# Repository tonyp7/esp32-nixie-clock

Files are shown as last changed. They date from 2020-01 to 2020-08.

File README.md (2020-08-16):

# esp32-nixie-clock

A smart nixie clock capable of automatically setting time and adjusting for timezones / summer time transitions.

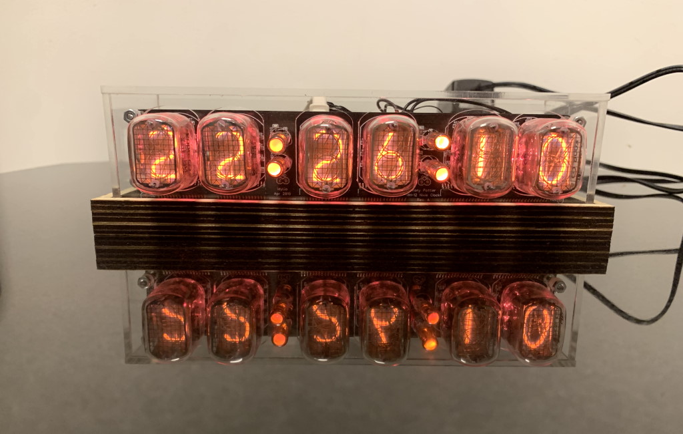
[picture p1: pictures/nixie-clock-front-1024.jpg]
Clock face


# Features

**Smart**

  - Time is set automatically through a web API
  - A webapp is provided to adjust wifi settings, timezone, backlights and display sleeping times
  
The wifi settings are managed by [esp32-wifi-manager](https://github.com/tonyp7/esp32-wifi-manager).

<p align="center">
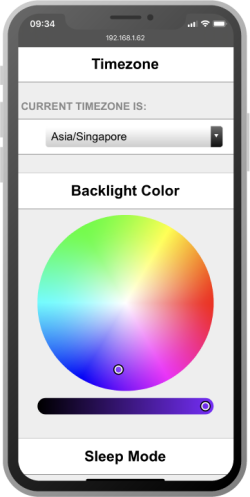
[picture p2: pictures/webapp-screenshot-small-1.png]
  
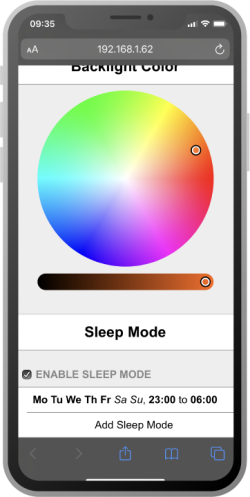
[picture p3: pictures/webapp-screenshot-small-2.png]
  
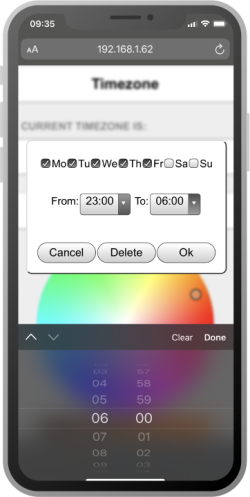
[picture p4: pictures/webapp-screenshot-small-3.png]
  
</p>

**A modern dispay driver**

  - SPI based driver
  - No multiplexing of nixies
  - No relying on old nixie drivers

Each pin is fully driven by its individual 300V NPN transistor.

**A robust high voltage converter**

 - A modern flyback converter with top of the line controller
 - No 555, no old 34063 trickery

The nixie clock is powered by a LT3757 controller and a big 1:10 transformer. The design can be found [here](https://github.com/tonyp7/170v-nixie-power-supply). The last thing you need is for your clock to catch fire!

# Repository structure

- bom: Bill of Materials for the PCBs
- nixie_clock_code: An esp-idf project to compile and flash on an ESP32
- pcb: PCB source files and renders for the clock
- pictures: A placeholder for the pictures you are seeing in this readme file
- schematics: Electronics schematics for the clock

# Photos

### Clock in its environment
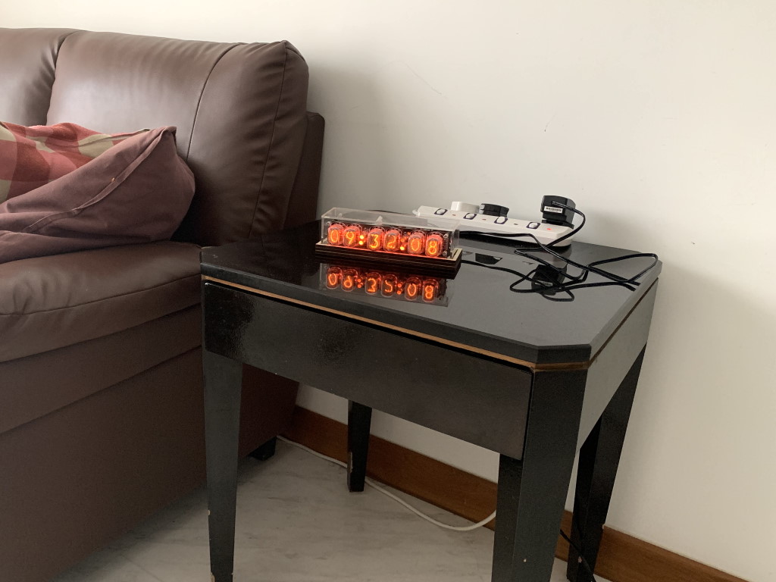
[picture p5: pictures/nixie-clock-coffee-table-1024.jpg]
Nixie Clock


### The clock face PCB
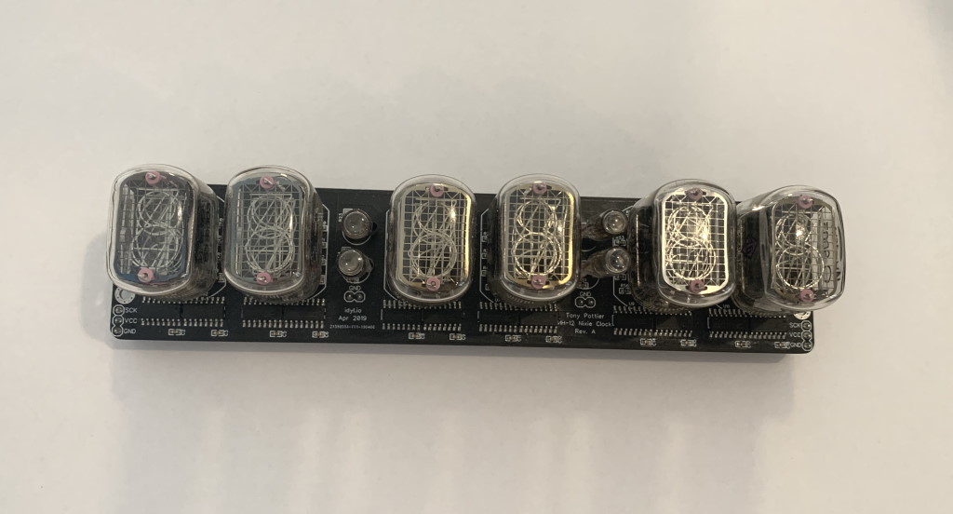
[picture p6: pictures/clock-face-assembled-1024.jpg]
Clock face PCB


### The logic board PCB
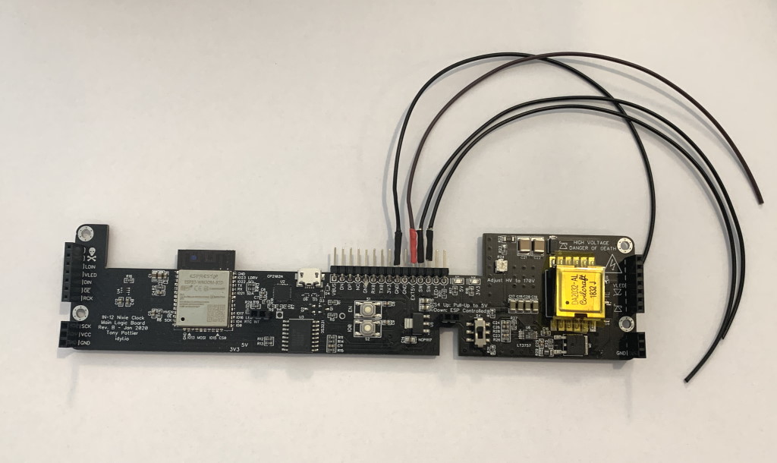
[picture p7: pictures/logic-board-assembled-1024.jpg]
Logic board PCB PCB


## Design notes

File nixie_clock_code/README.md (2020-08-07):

# Firmware for the esp32

This folder contains an esp-idf project for the esp32 powering the clock.

esp-idf 4.2+ is required to compile this code.

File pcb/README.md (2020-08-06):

# clock-face

Clock face assembled

# logic-board

Logic board assembled

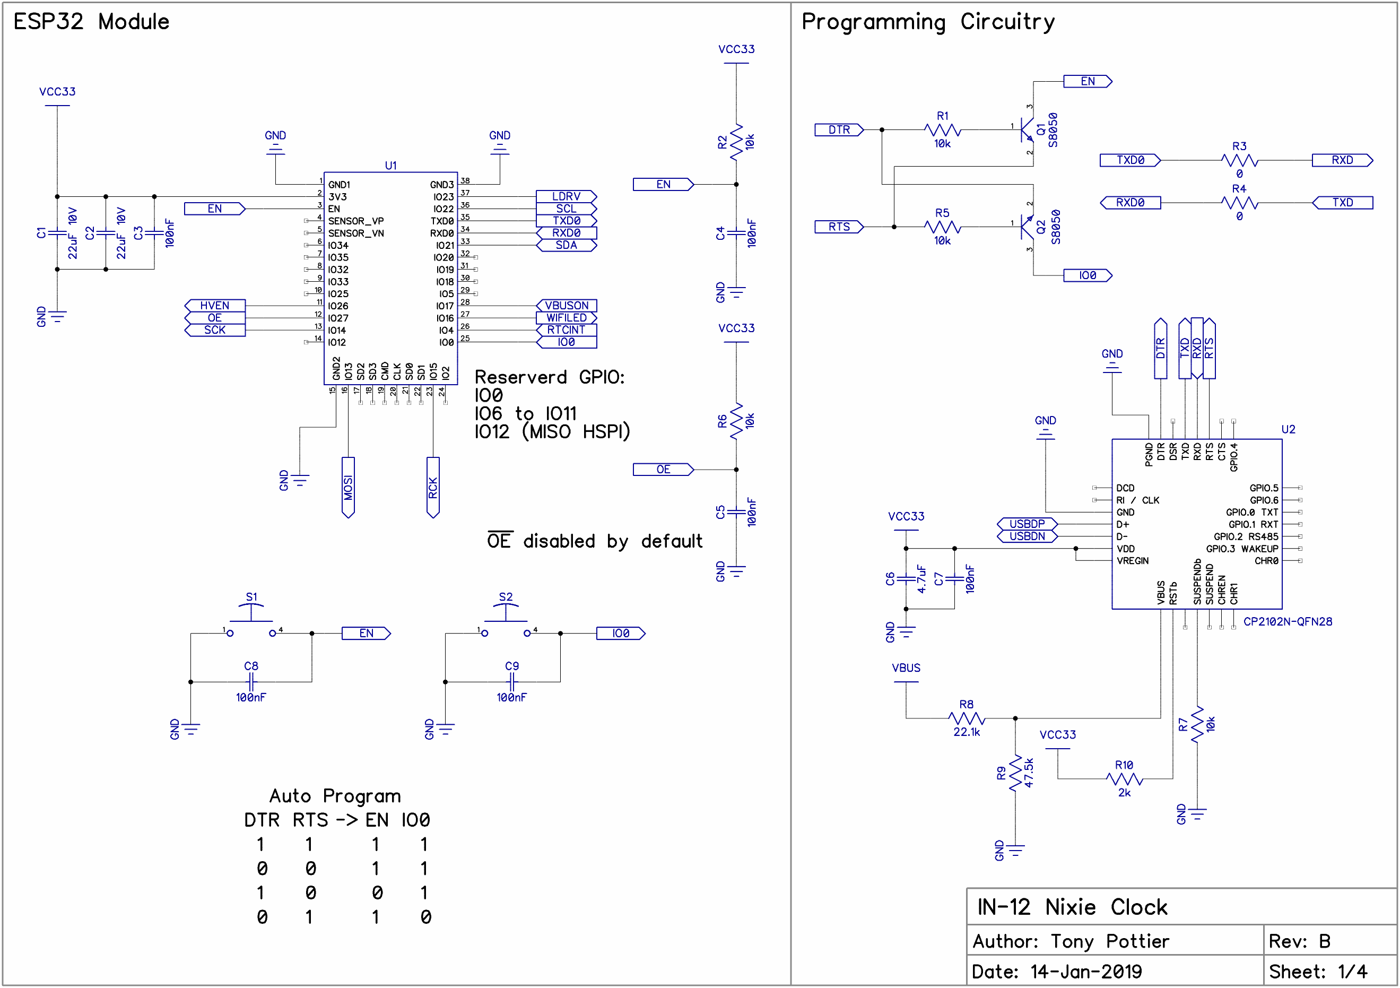
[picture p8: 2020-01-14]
schematics/logic-board/logic-board-schematics-sheet-1.png

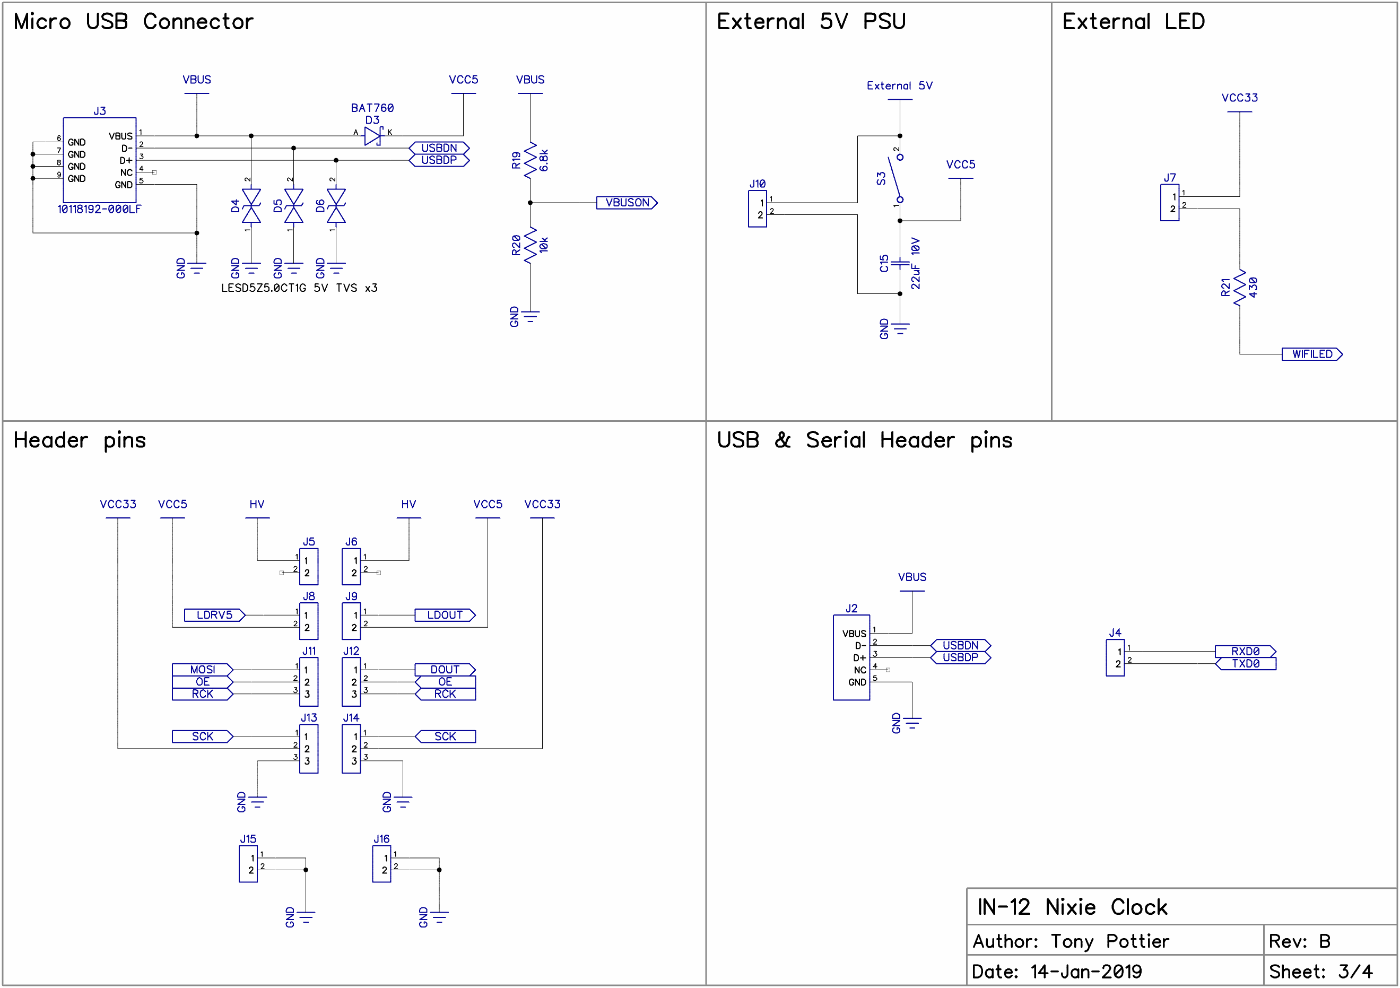
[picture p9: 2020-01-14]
schematics/logic-board/logic-board-schematics-sheet-3.png

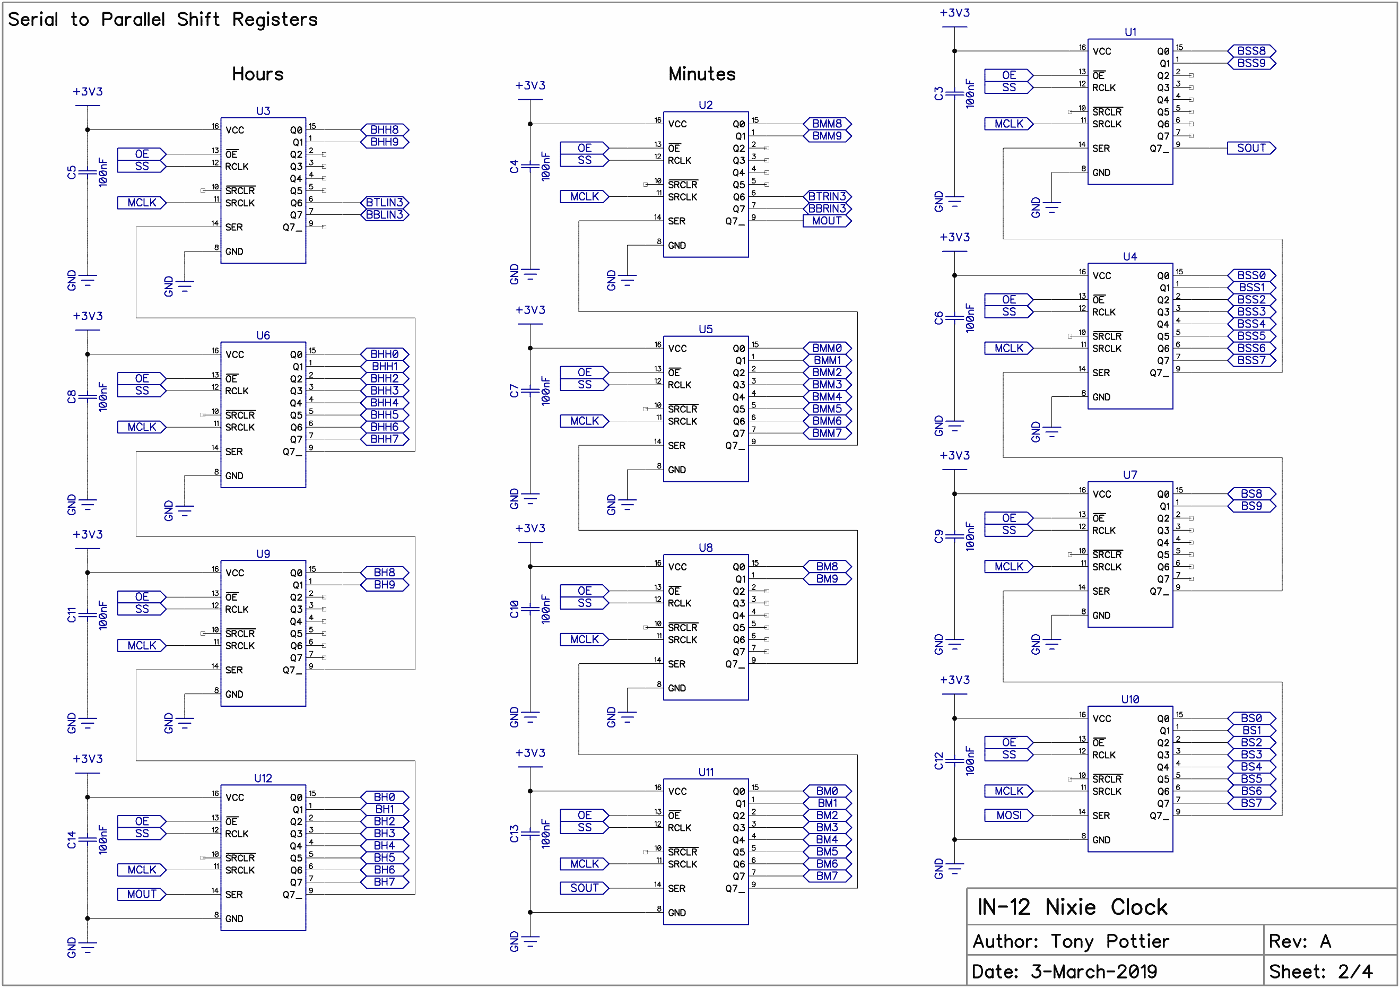
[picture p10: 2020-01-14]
schematics/clock-face/clock-face-schematics-sheet-2.png

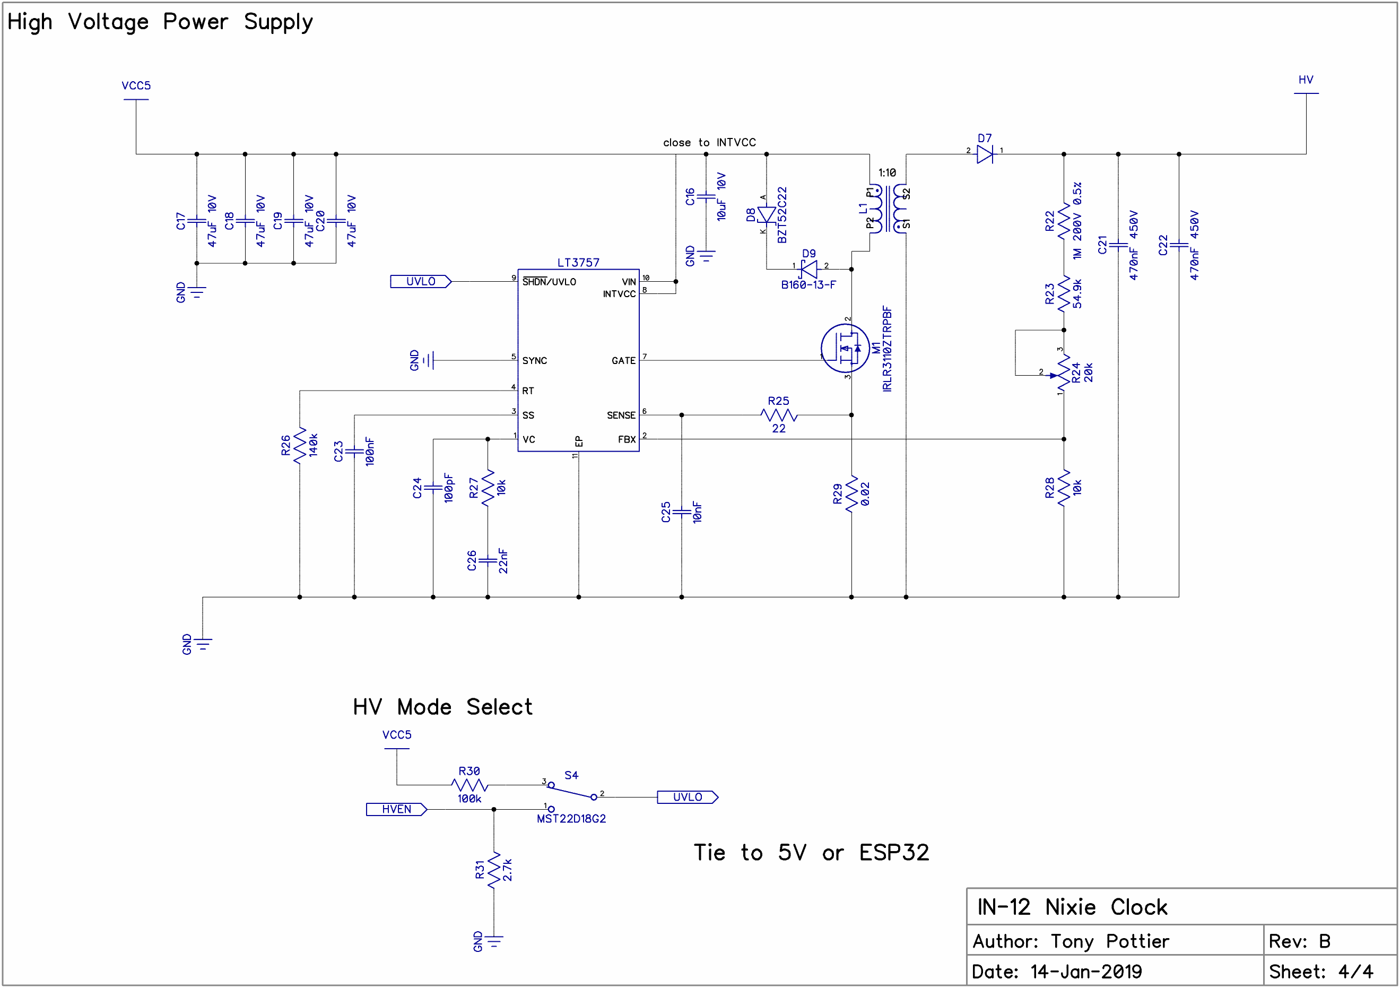
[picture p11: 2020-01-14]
schematics/logic-board/logic-board-schematics-sheet-4.png

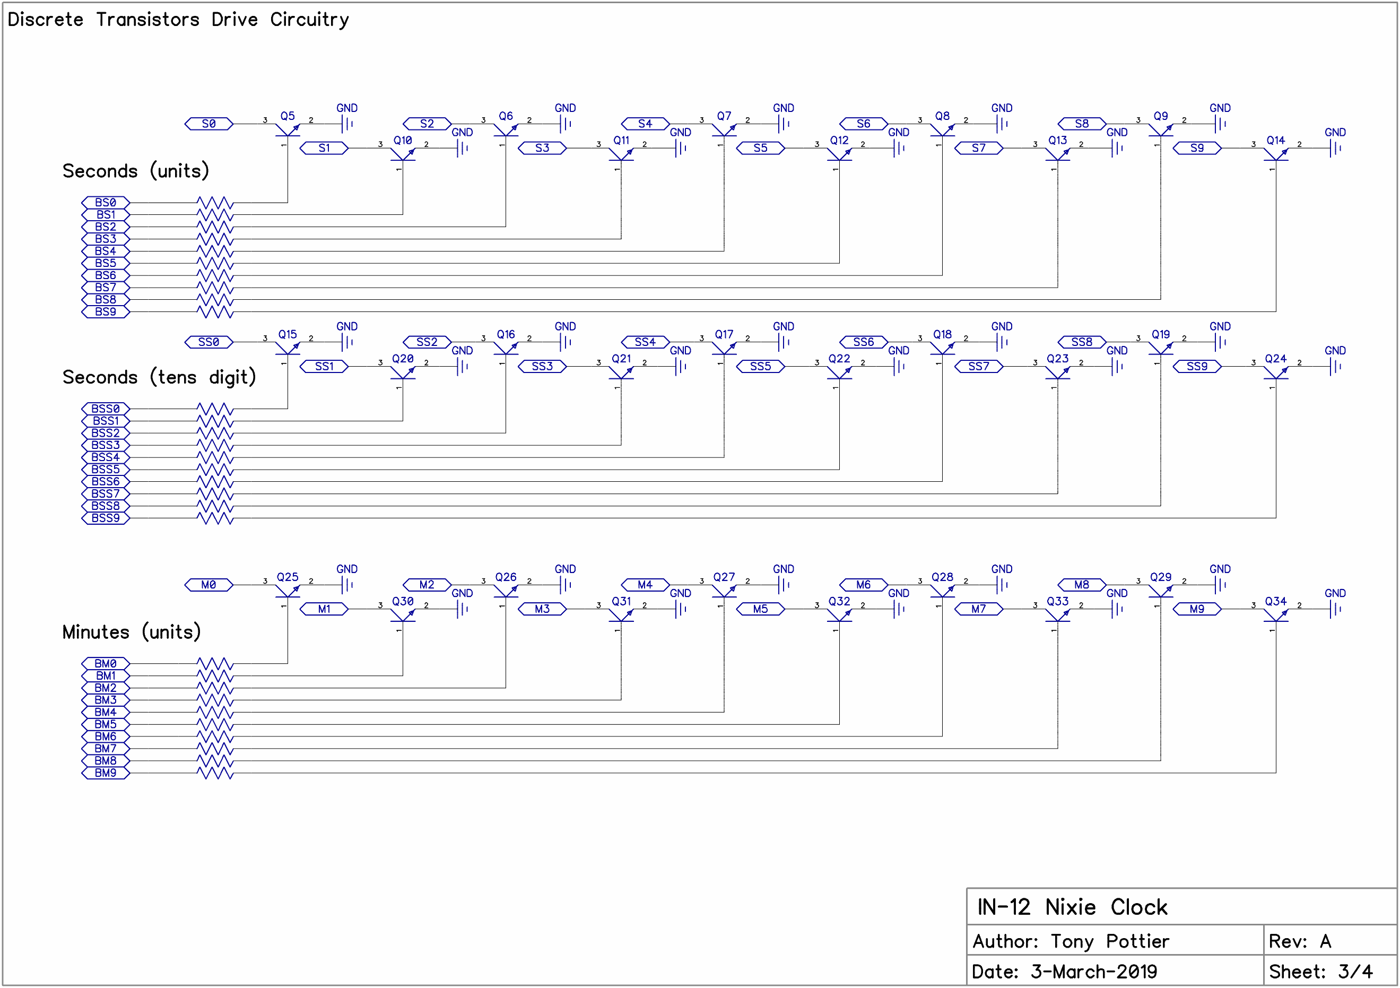
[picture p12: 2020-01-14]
schematics/clock-face/clock-face-schematics-sheet-3.png

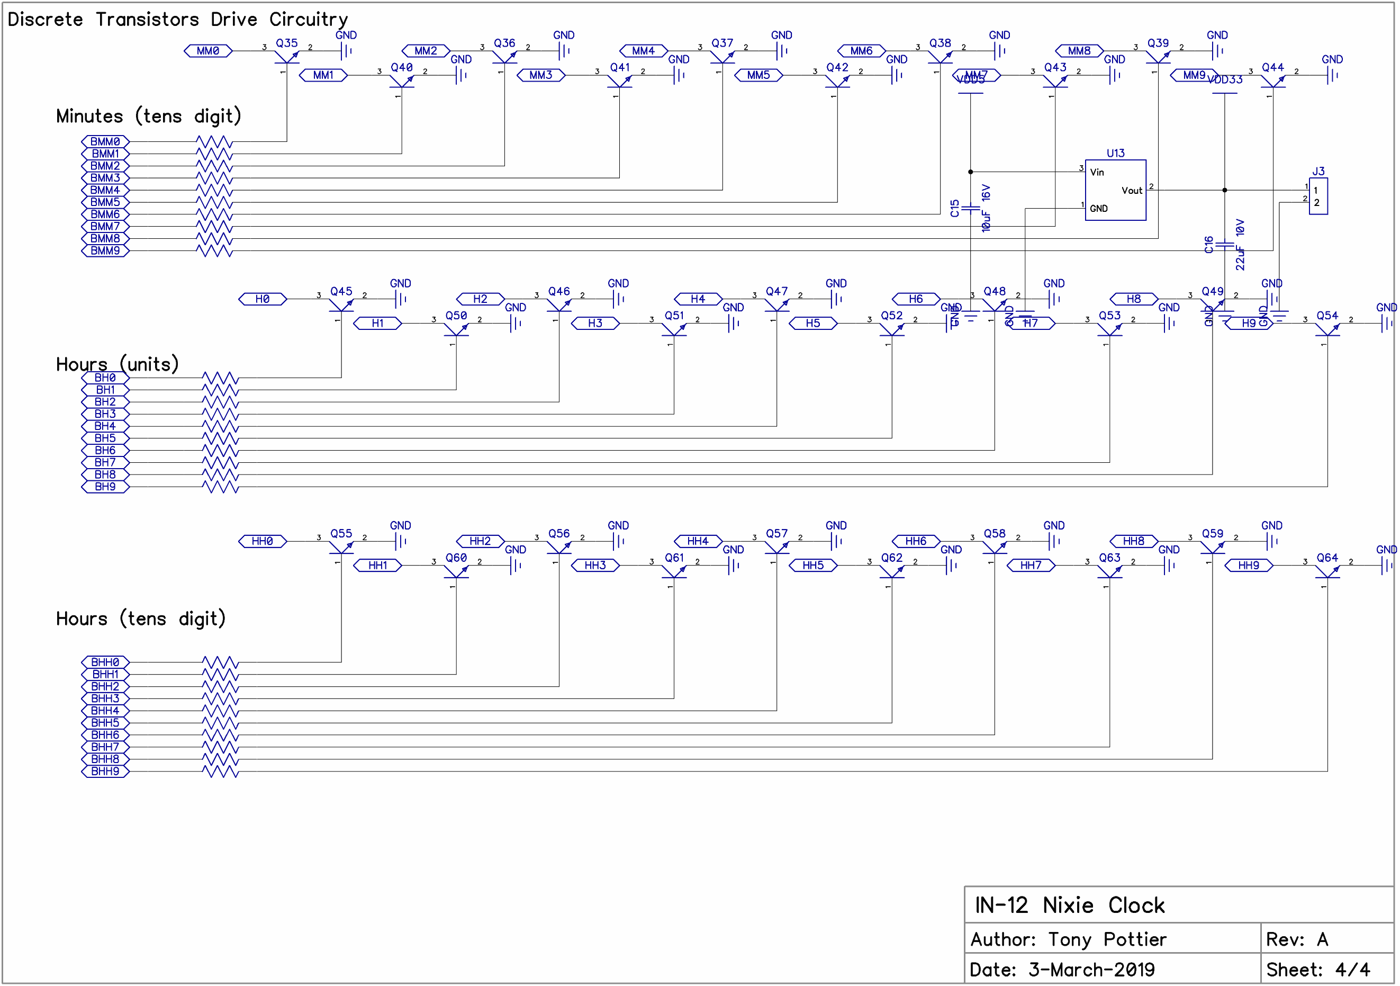
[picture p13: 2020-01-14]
schematics/clock-face/clock-face-schematics-sheet-4.png

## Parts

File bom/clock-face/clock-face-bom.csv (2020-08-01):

RefDes | Description | Package | Quantity | Manufacturer | Manufacturer Part Number
C3, C4, C5, C6, C7, C8, C9, C10, C11, C12, C13, C14 | 100nF 0603 50V X7R | 0603 | 12 | Yageo | CC0603KRX7R9BB104
N1, N2, N3, N4 | ??C-1 Nixie Tube | THT | 4 | Reflector (Sovtek) | INS-1
NX1, NX2, NX3, NX4, NX5, NX6 | ??-12A Nixie Tube | THT | 6 | Reflector (Sovtek) | IN-12A
Q1, Q2, Q3, Q4, Q5, Q6, Q7, Q8, Q9, Q10, Q11, Q12, Q13, Q14, Q15, Q16, Q17, Q18, Q19, Q20, Q21, Q22, Q23, Q24, Q25, Q26, Q27, Q28, Q29, Q30, Q31, Q32, Q33, Q34, Q35, Q36, Q37, Q38, Q39, Q40, Q41, Q42, Q43, Q44, Q45, Q46, Q47, Q48, Q49, Q50, Q51, Q52, Q53, Q54, Q55, Q56, Q57, Q58, Q59, Q60, Q61, Q62, Q63, Q64 | Bipolar (BJT) Transistor NPN 300V 500mA 50MHz 240mW Surface Mount SOT-23-3 | SOT-23-3 | 64 | ON Semiconductor | MMBTA42
R1, R2, R3, R4, R5, R6 | 20k 1206 1/4W 1% | 1206 | 6 | Yageo | RC1206FR-0720KL
R7, R8, R9, R10 | 100k 1206 1/4W 1% | 1206 | 2 | Yageo | RC1206FR-07100KL
R11, R12, R13, R14, R15, R16, R17, R18, R19, R20, R21, R22, R23, R24, R25, R26, R27, R28, R29, R30, R31, R32, R33, R34, R35, R36, R37, R38, R39, R40, R41, R42, R43, R44, R45, R46, R47, R48, R49, R50, R51, R52, R53, R54, R55, R56, R57, R58, R59, R60, R61, R62, R63, R64, R65, R66, R67, R68, R69, R70, R71, R72, R73, R74 | 20K 0603 1% | 0603 | 64 | Yageo | RC0603FR-0720KL
U1, U2, U3, U4, U5, U6, U7, U8, U9, U10, U11, U12 | SNx4HC595 8-Bit Shift Registers | SOIC-16 | 12 | Texas Instruments | SN74HC595D

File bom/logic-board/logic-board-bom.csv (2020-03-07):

RefDes | Description | Package | Quantity | Manufacturer | Manufacturer Part Number
C1, C2, C13, C14, C15 | 22uF 10V X5R 0805 | 0805 | 5 | Samsung | CL21A226MPQNNNE
C3, C4, C5, C8, C9, C10, C11, C12, C23 | 100nF 50V X7R 0603 | 0603 | 9 | Yageo | CC0603KRX7R9BB104
C6 | 4.7UF 10V X5R 0402 | 0402 | 1 | Samsung | CL05A475KP5NRNC
C7 | 100nF 16V X7R 0402 | 0402 | 1 | Samsung | CL05B104MO5NNNC
C16 | 10uF 10V X5R 0603 | 0603 | 1 | Samsung | CL10A106MP8NNNC
C17, C18, C19, C20 | 47uF 10V X5R 1206 | 1206 | 4 | Taiyo Yuden | LMK316BJ476ML-T
C21, C22 | 470nF 450V X7R 1812 | 1812 | 2 | Holy Stone | C1812X474K451T
C24 | 100pF 50V X7R 0603 | 0603 | 1 | Yageo | CC0603KRX7R9BB101
C25 | 10nF 50V X7R 0603 | 0603 | 1 | Yageo | CC0603KRX7R9BB103
C26 | 22nF 50V X7R 0603 | 0603 | 1 | Yageo | CC0603KRX7R9BB223
D1, D2 | LED Red 618~625nm 25~45mcd@5mA Surface Mount 0805 RoHS | 0805 | 2 | ARKLED(Wuxi ARK Tech Elec) | D-R080508L3-KS2
D3 | 30V 1A 550mV @ 1A SOD-323 Schottky Barrier Diodes (SBD) RoHS | SOD-323 | 1 | Diodes Incorporated | BAT760-7
D4, D5, D6 | Bidirectional 5V 5.6V 18.6V 9.4A (8/20us) SOD-523 Diodes | SOD-523 | 3 | Leshan Radio | LESD5D5.0CT1G
D7 | Diodes - Rectifiers - Hyperfast 400V 1A 1.3V @ 1A 35ns SMA(DO-214AC) RoHS | SMA | 1 | ON Semicon | ES1G
D8 | 22V ±6% 500mW 100nA @ 15.4V SOD-123 Zener Diodes RoHS | SOD-123 | 1 | Diodes Incorporated | BZT52C22-7-F
D9 | 60V 1A 700mV @ 1A SMA(DO-214AC) Schottky Barrier Diodes (SBD) RoHS | SMA | 1 | Diodes Incorporated | B160-13-F
J3 | MICRO USB CONN, 2.0 TYPE B, RCPT, SMT | SMD | 1 | Amphenol ICC | 10118192-000LF
JBAT | CR2032 Battery Holder | THT | 1 | Q&J | BS-2-1
L1 | 3A Signal Transformer DA2032 | SMD | 1 | Coilcraft | DA2032-ALB
M1 | N Channel 100V 42A 2.5V @ 100uA 14 m? @ 38A,10V 140W TO-252-2(DPAK) MOSFET RoHS | TO-252-2(DPAK) | 1 | International Rectifier | IRLR3110ZTRPBF
Q1, Q2 | Transistors (NPN/PNP) NPN 500mA 25V SOT-23(SOT-23-3) RoHS | SOT-23 | 2 | Guangdong Hottech | S8050
R1, R2, R5, R6, R11, R14, R15, R16, R20, R27, R28 | 10k 0603 1% | 0603 | 11 | Yageo | RC0603FR-0710KL
R3, R4 | 0R 0603 1% | 0603 | 2 | Yageo | RC0603FR-0710KL
R7 | 10k 0402 1% | 0402 | 1 | Yageo | RC0402FR-0710KL
R8 | 22.1k 0402 1% | 0402 | 1 | Yageo | RC0402FR-0722K1L
R9 | 47.5k 0402 1% | 0402 | 1 | Yageo | RC0402FR-0747K5L
R10 | 2k 0402 1% | 0402 | 1 | Yageo | RC0402FR-072KL
R12, R13 | 2k7 0603 1% | 0603 | 2 | Yageo | RC0603FR-072K7L
R17, R18 | 1k 0603 1% | 0603 | 2 | Yageo | RC0603FR-071KL
R19 | 6.8k 0603 1% | 0603 | 1 | Yageo | RC0603FR-076K8L
R21 | 430R 0603 1% | 0603 | 1 | Yageo | RC0603FR-07430RL
R22 | 1M 200V 0.5% | 1206 | 1 | ROHM Semicon | MCR18EZPD1004
R23 | 54.9k | 0603 | 1 | Yageo | RC0603FR-0754K9L
R24 | Precision Potentiometer 20KOhms ±20% ±100ppm/? 3313J RoHS | 3313J | 1 | BOURNS | 3313J-1-203E
R25 | 22R 0603 1% | 0603 | 1 | Yageo | RC0603FR-0722RL
R26 | 140k 0603 1% | 0603 | 1 | Yageo | RC0603FR-07140KL
R29 | 0.02 ±1% 1W 1206 Chip Resistor | 1206 | 1 | Yageo | PE1206FRF470R02L
R30 | 100k | 0603 | 1 | Yageo | RC0603FR-07100KL
R31 | 2.7k | 0603 | 1 | Yageo | RC0603FR-072K7L
S1, S2 | PST-NO 50mA @ 6VDC Top Actuated Standard SMD Tactile Switches RoHS | SMD | 2 | BOOMELE(Boom Precision Elec) | 4*4*1.7
S4 | SMD,9.1x3.6mm Toggle Switches RoHS | SMD | 1 | SHOU HAN | MST22D18G2
U1 | ESP32-WROOM32 | SMD | 1 | Espressif | ESP32-WROOM32
U2 | USB ICs 1/1 3Mbps 3V ~ 3.6V QFN-28 | QFN-28 | 1 | Silicon Labs | CP2102N-A01-GQFN28R
U3 | Real-time Clock | SOIC-16 300mil | 1 | Maxim Integrated | DS3231SN#T&R
U4 | Transceivers, voltage-level SC-70-6(SOT-363) 74 Series RoHS | SC-70-6 | 1 | Texas Instruments | SN74LVC1T45DCKR
U5 | Fixed 18V 3.3V 1A SOT-223 Low Dropout Regulators(LDO) RoHS | SOT-223 | 1 | ON Semicon | NCP1117LPST33T3G
U6 | MSOP-10_EP Switching Controllers RoHS | MSOP-10EP | 1 | Analog Devices | LT3757AIMSE#PBF

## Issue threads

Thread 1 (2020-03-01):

Missing source files

Blaster1920, 2020-03-01:
Hi there,
I was interested in replicating your project for personal use, but I couldn't find anywhere in the repo the source files for the PCB and schematics.
Would you be able to upload them?
Thanks in advance.

tonyp7, 2020-03-02:
Hello,

Yes I need to upload a few more files --including pictures of the final clock.  I'll do that this week!

Cheers

tonyp7, 2020-03-02:
I added gerber files. I don't understand your comment about schematics though, it's all there (?)

Blaster1920, 2020-03-02:
Hi there,
thanks for the reply and the gerbers.
What I meant is that it's missing the source files for the schematics,  the proprietary files of the CAD you've used (eg. Kicad .sch).

tonyp7, 2020-03-07:
I pushed the original file (Dip Trace) in /schematics and added the BOM. Good luck!

Blaster1920, 2020-03-07:
> I pushed the original file (Dip Trace) in /schematics and added the BOM. Good luck!

Thanks for your help! I'll give it a try.

Closed 2020-07-21.

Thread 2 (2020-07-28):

Is this project open source?

rudinikun, 2020-07-28:
Hi Tony,

I see you are working on an extraordinary project. I want to ask if this project is open source, in the sense that I can print the PCB that you made?

Thank you,
Rudini

tonyp7, 2020-07-28:
Absolutely yes it is open source! You can have the PCB made freely.

Also I know this repository is a bit bare right now but that's because it's mostly a personal project. I'll add some pictures soon!

rudinikun, 2020-07-28:
Awesome, can't wait for that. Also can you please share the BOM for clock face. Thank you Tony

tonyp7, 2020-07-29:
BOM is added

tonyp7, 2020-07-29:
I realize it's missing the WS2812 leds which were added later -- I need to update the schematics and BOM to match the PCB

rudinikun, 2020-07-30:
Hi Tony,

Thank you for adding BOM. I am very unfamiliar with hardware, if I print a PCB and install all electronic components, the next step is to upload the code into ESP32, is that right Tony, Are there other devices that must be prepared, please advise?

Thank you,
Rudini

tonyp7, 2020-07-30:
That's right. It's pretty much assemble the PCBs and upload the firmware to ESP32.

That being said if you are a beginner in that space I'd strongly advise you to not start with this. This project is still very much work in progress so the code is not complete; and the PCBs themselves might be challenging as they contain very small parts (0402 and 0.5mm pitch components).

Closed 2020-08-01.

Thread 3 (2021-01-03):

Hi Tony, I found that the "\ PCB \ Logic-Board" file in the project does not match with the photo. Could you please open the latest version of the file?thank you

xb98922, 2021-01-03:

tonyp7, 2021-01-03:
can you point out some differences?

xb98922, 2021-01-03:
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
According to the screen printing of THE PCB, Gerber file was made in 2019, and the PCB in the photo was made in 2020.It looks like the components have increased

xb98922, 2021-02-27:
> 你能指出一些区别吗？

Hello, I really like this project and I'm ready to start DIY. I'm looking forward to your reply

will675, 2024-01-11:
Hi,

it looks like the photo is of Rev B, but the gerber files are for Rev A. Is it possible to get the latest gerber files please? Very keen to give this a go!

Thanks

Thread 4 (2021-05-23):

No output on RMT pin?

N9SHazpnhYW, 2021-05-23:
I'm trying to utilize the code in your WIFI manager server for RGB LED control.  I've verified FastLED library to work with my hardware, however when I try to use this code, I dont seem to get any actual output on the GPIO pin.  There is no data on the pin when I check with an oscilloscope.  Data looks fine on the scope with FastLED.

I am able to successfully start the WIFI server, connect, etc...  I can also see the terminal printout of the RGB selection when I choose a color on the color wheel.  The only problem is, there is no data being sent to the pin....

I am using pin 25:
`#define WS2812_DATA_GPIO		25`

I've verified that I am hitting this case in the state machine with a terminal printout:
```
case CLOCK_MESSAGE_BACKLIGHTS_CONFIG:{
					;rgb_t rgb;
					rgb.num = (uint32_t)msg.param;
					if(clock_config.display.led_color.num != rgb.num){
						clock_config.display.led_color = rgb;
						// display_turn_on();
						ESP_LOGI(TAG,"SET_BACKLIGHT_COLOR()");
						// ws2812_set_backlight_color(clock_config.display.led_color);
						xTaskNotifyGive( clock_task_save_nvs );
					}
					}
					break;
```
I also attempted to call `ws2812_set_backlight_color(clock_config.display.led_color);` within that case to manually send data.

`I (21195) ws2812: Received R:140 G:161 B:255
I (21205) http_server: POST /backlights/
I (21205) webapp: setting backlight!
I (21215) clock: got new led color
I (21215) ws2812: Received R:128 G:138 B:255
I (21215) clock: SET_BACKLIGHT_COLOR()
I (21225) ws2812: Received R:128 G:138 B:255`

Any help would be greatly appreciated....thanks in advance

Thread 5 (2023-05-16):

Board revision mismatch

RyanChai, 2023-05-16:
I think someone already raised this issue, but the discussion went silent. The Gerber file is still on revision 1 while all the other folders like the BOM, schematics, and photos are already in revision 2. Since there's no original project files, it would be really hard to update the PCB layout myself without recreating it from scratch. Would it be possible to update the Gerber files to Rev2? Thank you!!

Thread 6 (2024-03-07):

clock-face PCB for other typs of nixie tubes

asdvbkjcd, 2024-03-07:
Hi Tony, I would like to know, if the original PCB and schematic files, at  least of the clock-face, are available, too, regardless if they are from Kicad, Alttium. Orcad or any other software. I have a lot of conversion possibilities. Background of this question: I have only (since many years) nixie tubes of the type ZM1020/QS30. So I have to adapt the clock-face board. I would save a lot of time, if I could start with the original Schematic and PCB-files. If you want, I can publish the results here.
By the way, I searched Internet for many hours for useful concepts for nixie tube clocks. Yours seems to be by far the best for me. Well-established, low cost hardware, precise RTC, controlled by Internet time, and comfortable settings via mobile.  No multiplexed tubes and a secure way to handle the high voltage by single transistors. A very professional looking PCB and a compact design -seperate PCBs for controler and display! Nearly perfect for my wishes (beside the wrong nixie tubes :D)
I don't know, if this is allowed here: you can send it directly to me eksbl@web.de too.

asdvbkjcd, 2024-03-13:
Here are somec additional information:
In the meantime you can get a suitable  transformer (for 170V genaration) on Aliexpress Not the one from coilcraft, but a TDK ( DCT15EFD-U44S003). This one is in the recommandation list of LinPartially is the transformer even availabe forear Technologies too! Partially is the transformer even available in single pieces for a reasonable price.
BTW my EDA-system is Diptrace! :) Do you have another webside in the meantime instead of idyl.io?

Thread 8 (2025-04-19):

Gerber files for revB PCB

adryanyd, 2025-04-19:
Hi Tony,
Can you please post gerber files for rev B logic board?
The ones that are now, Rev A  are missing usb conector and programming circuitry.
I would like to build this one as seems really welll done.
Thanks

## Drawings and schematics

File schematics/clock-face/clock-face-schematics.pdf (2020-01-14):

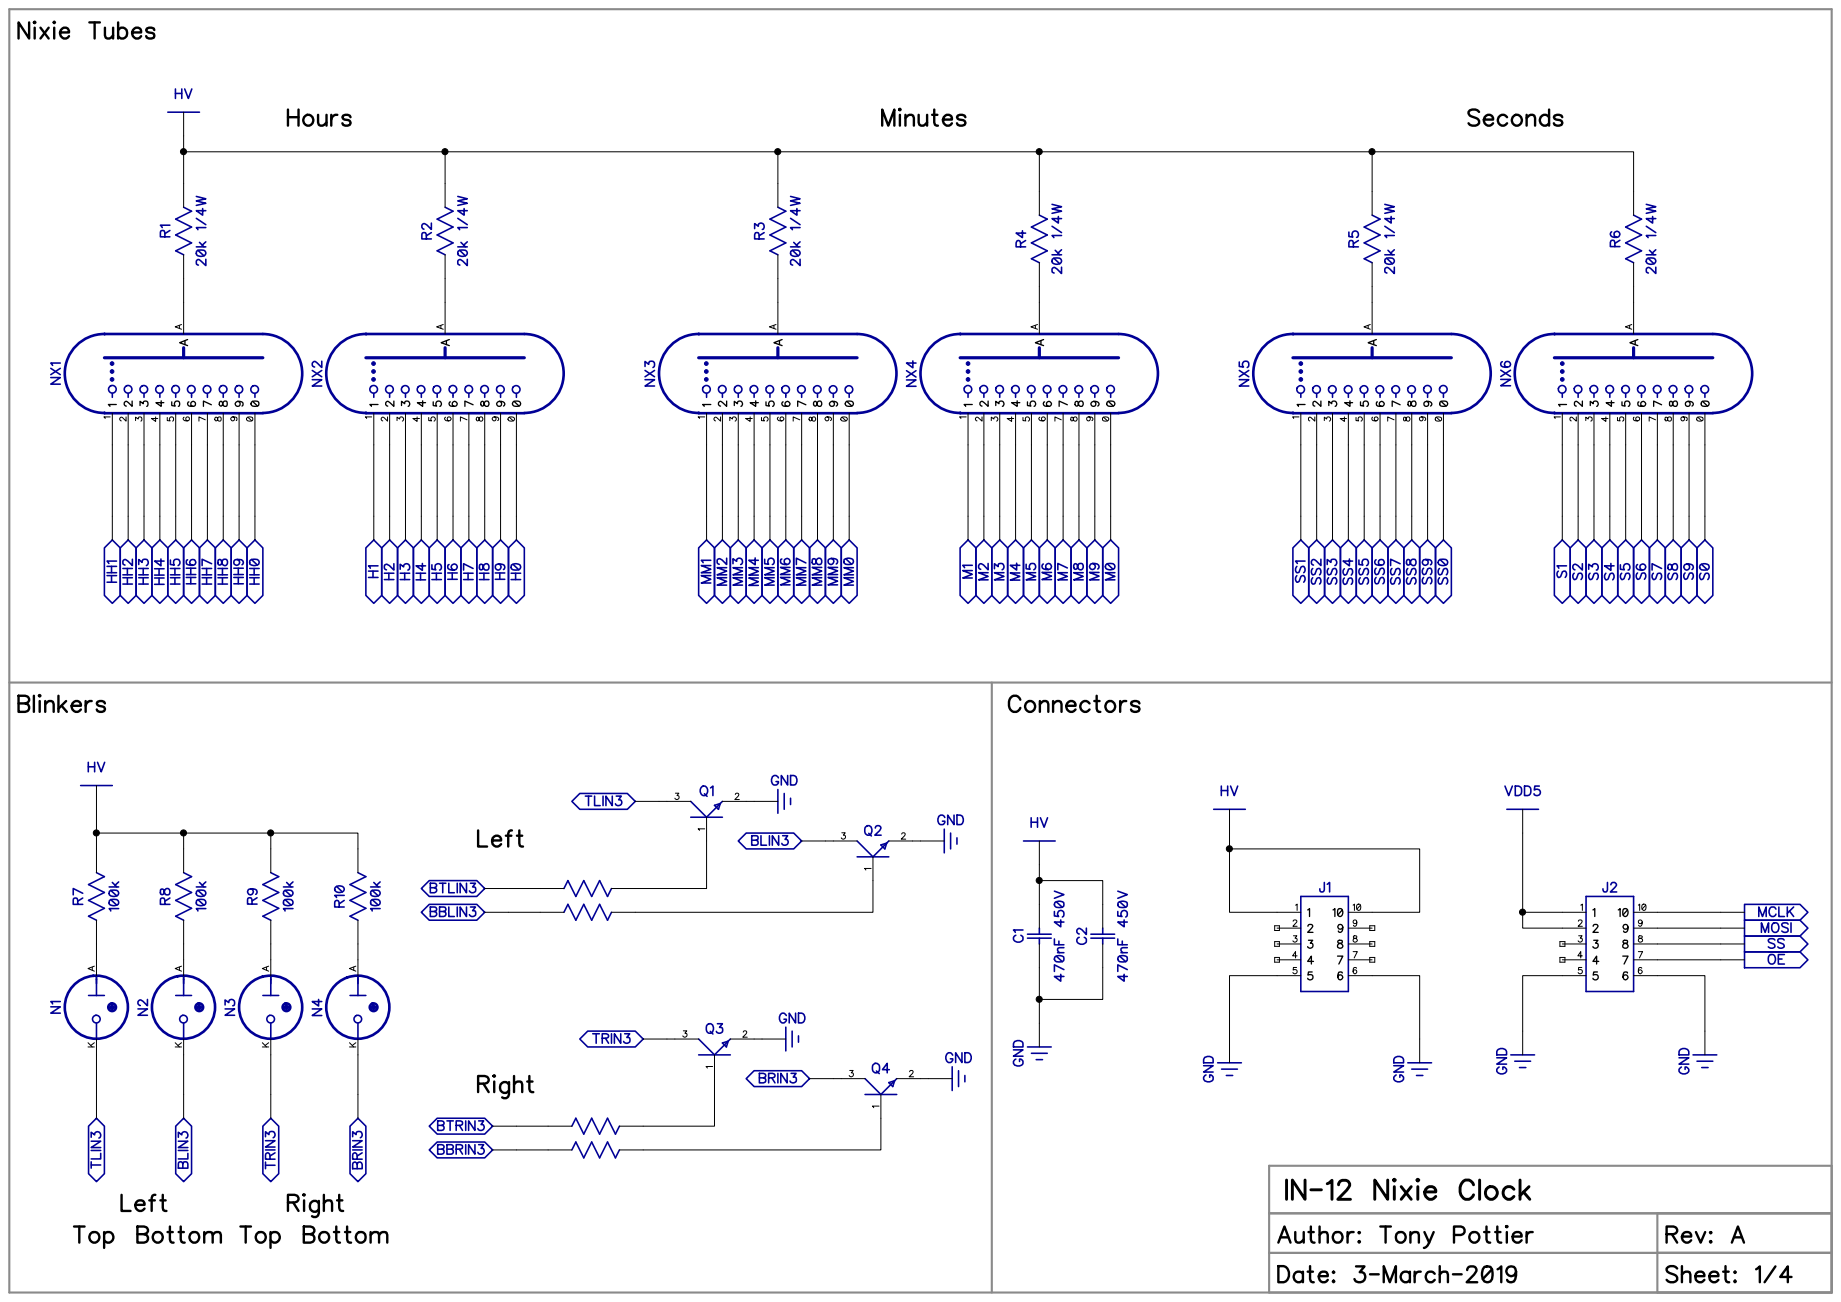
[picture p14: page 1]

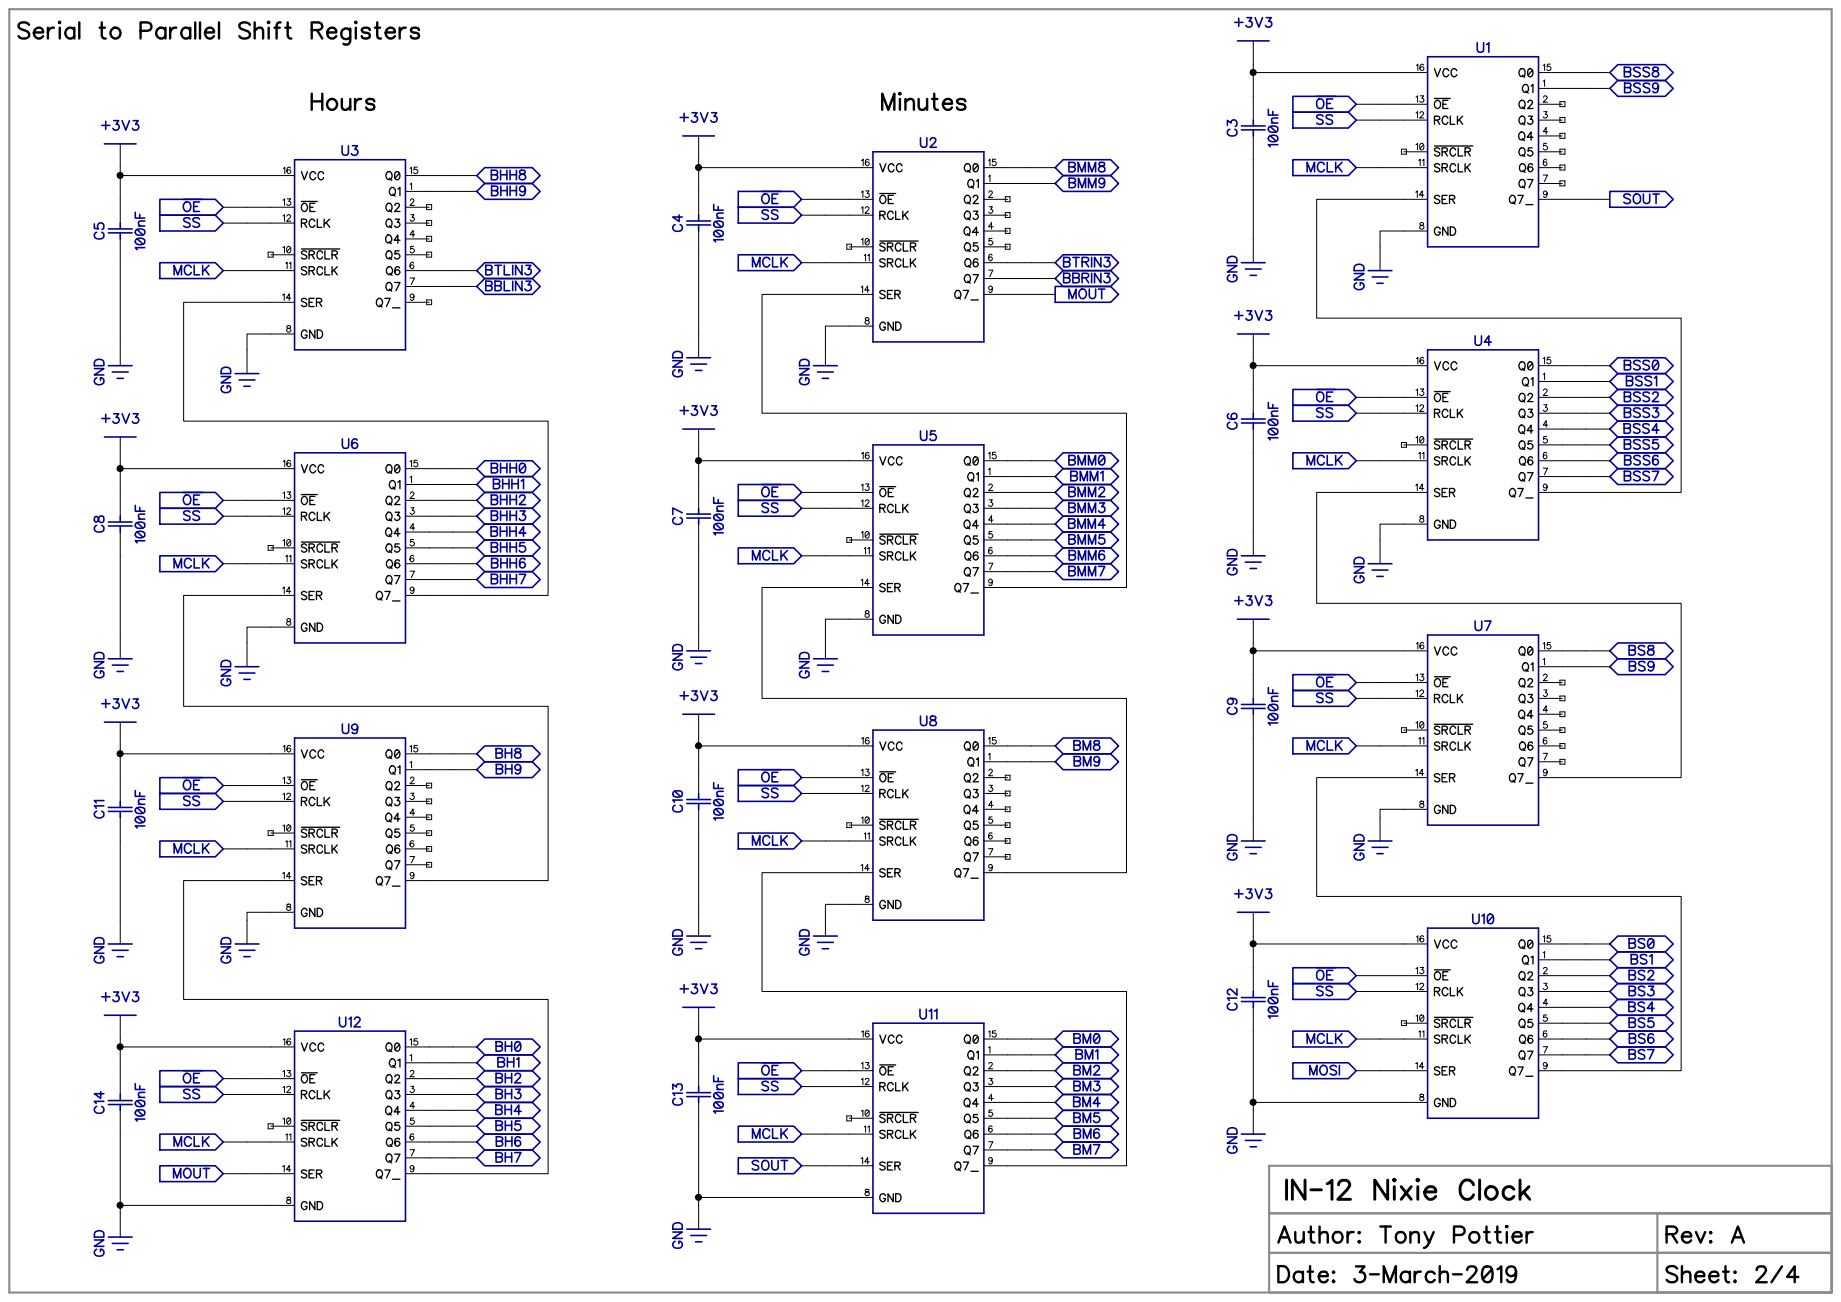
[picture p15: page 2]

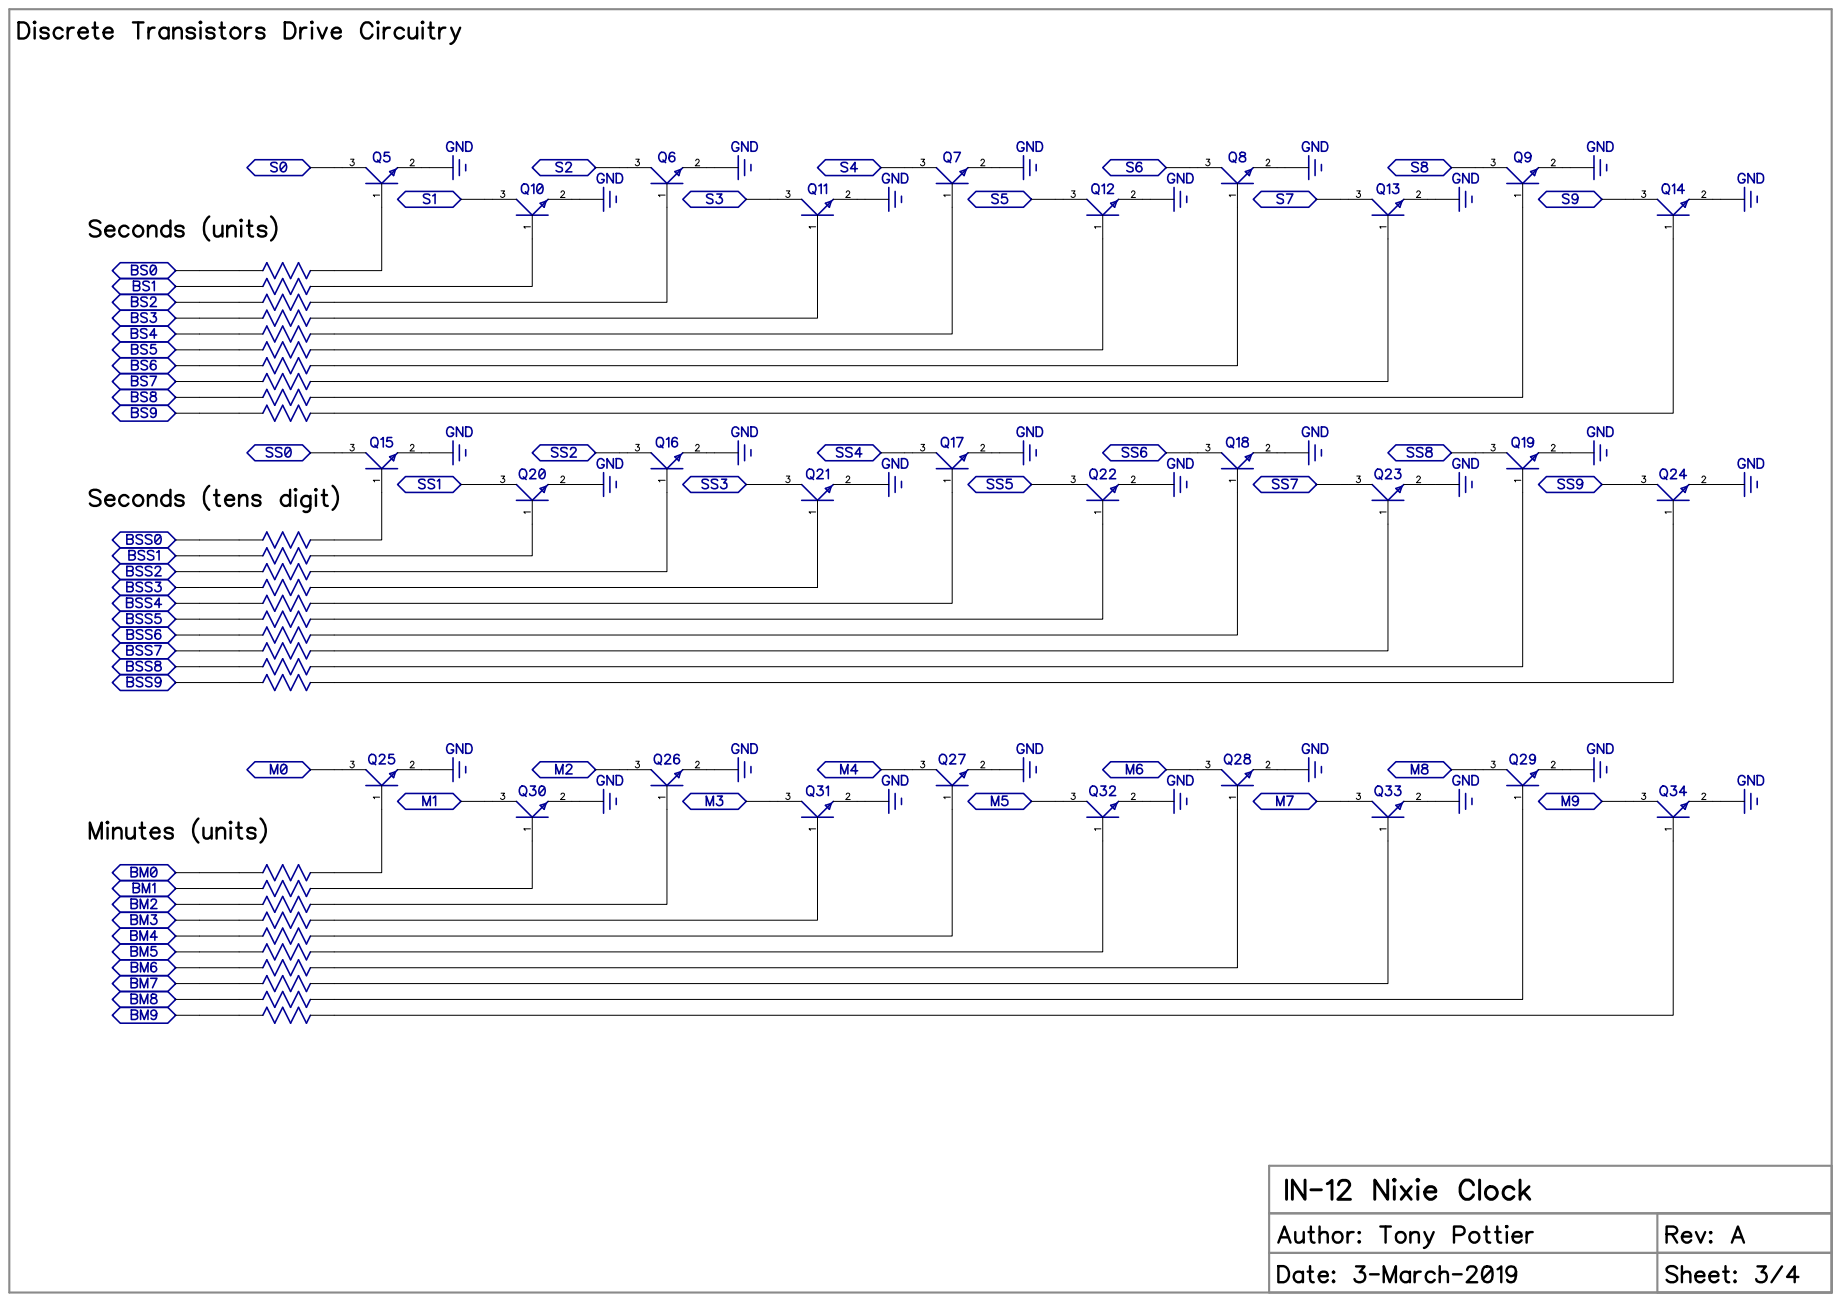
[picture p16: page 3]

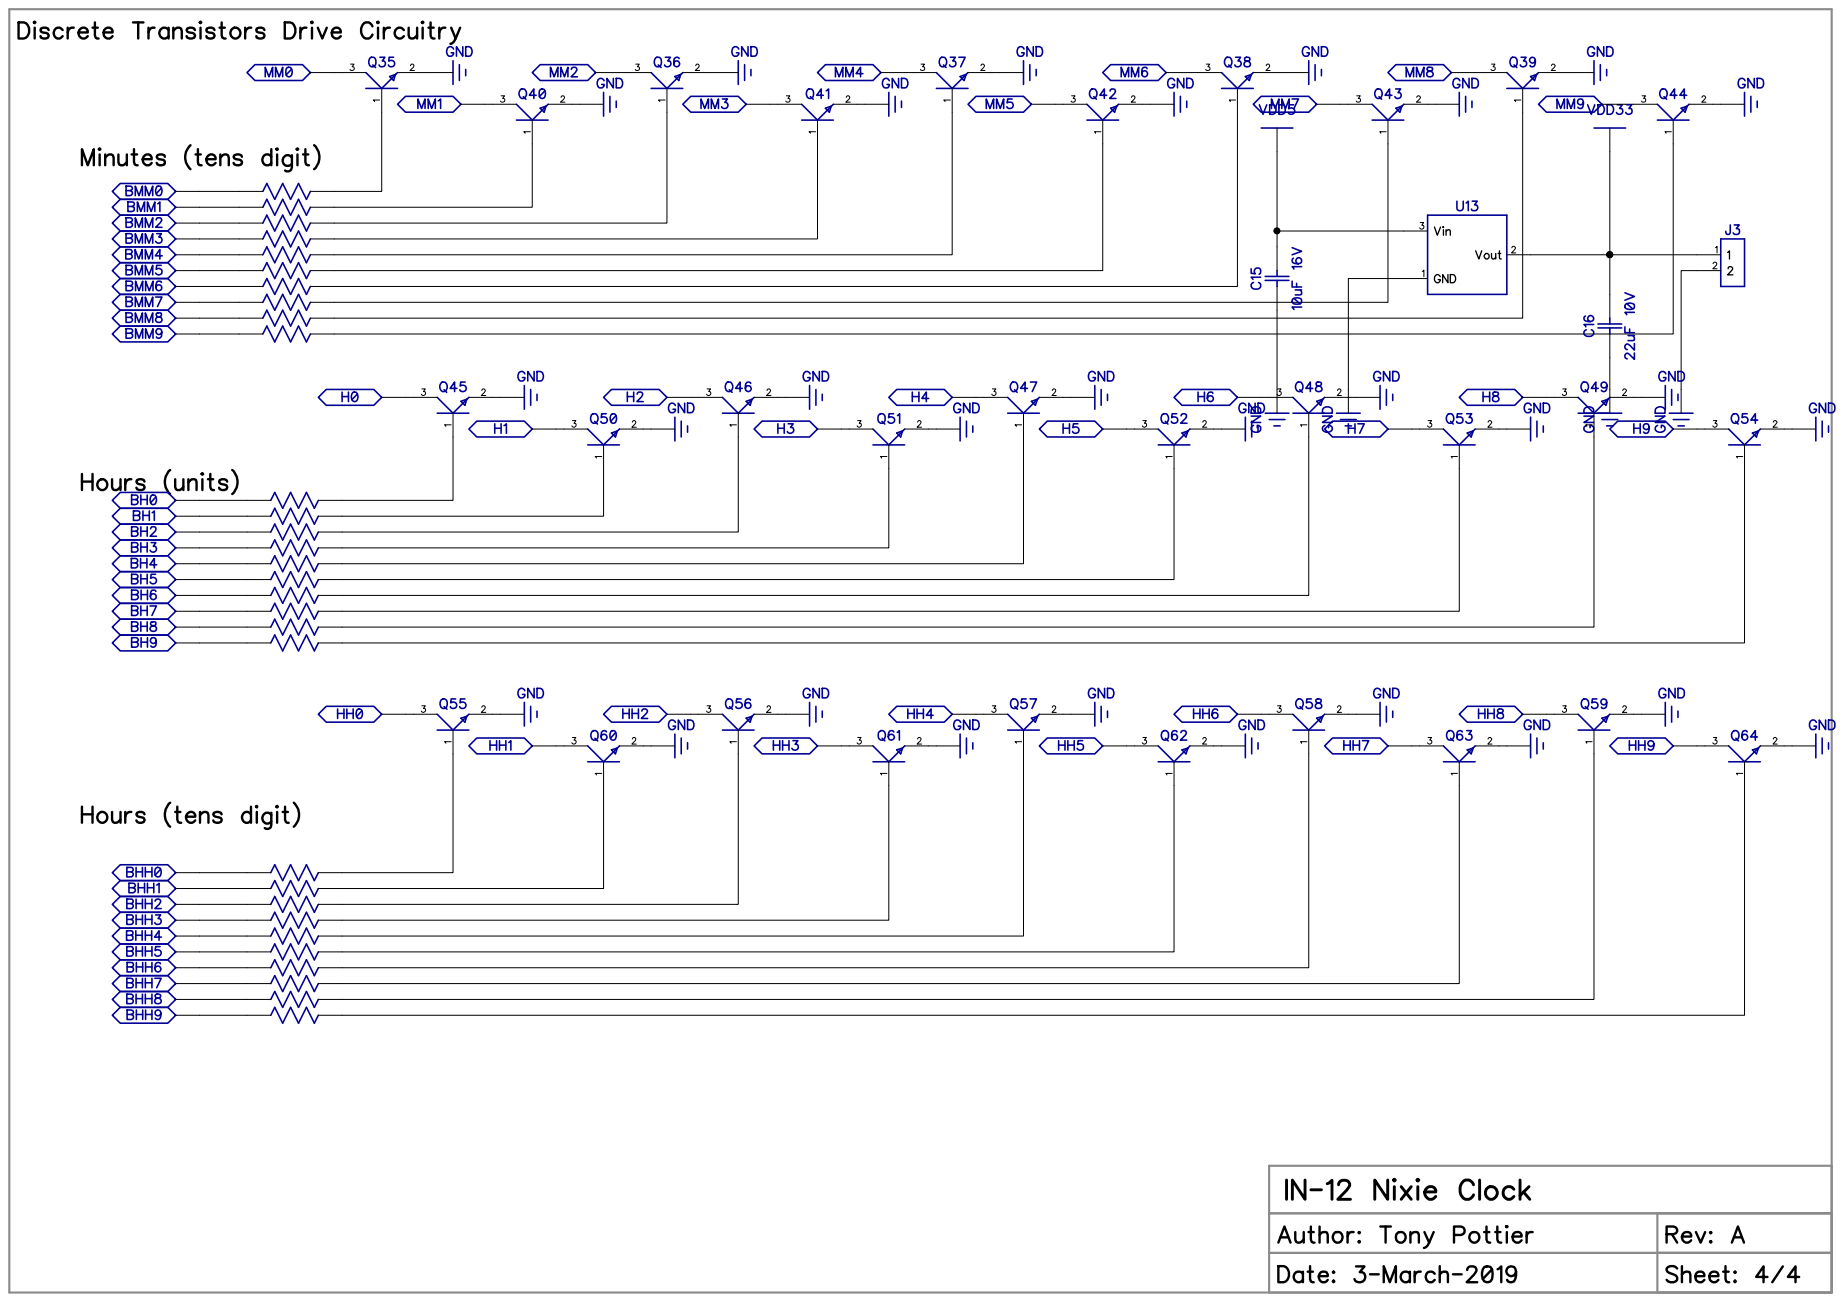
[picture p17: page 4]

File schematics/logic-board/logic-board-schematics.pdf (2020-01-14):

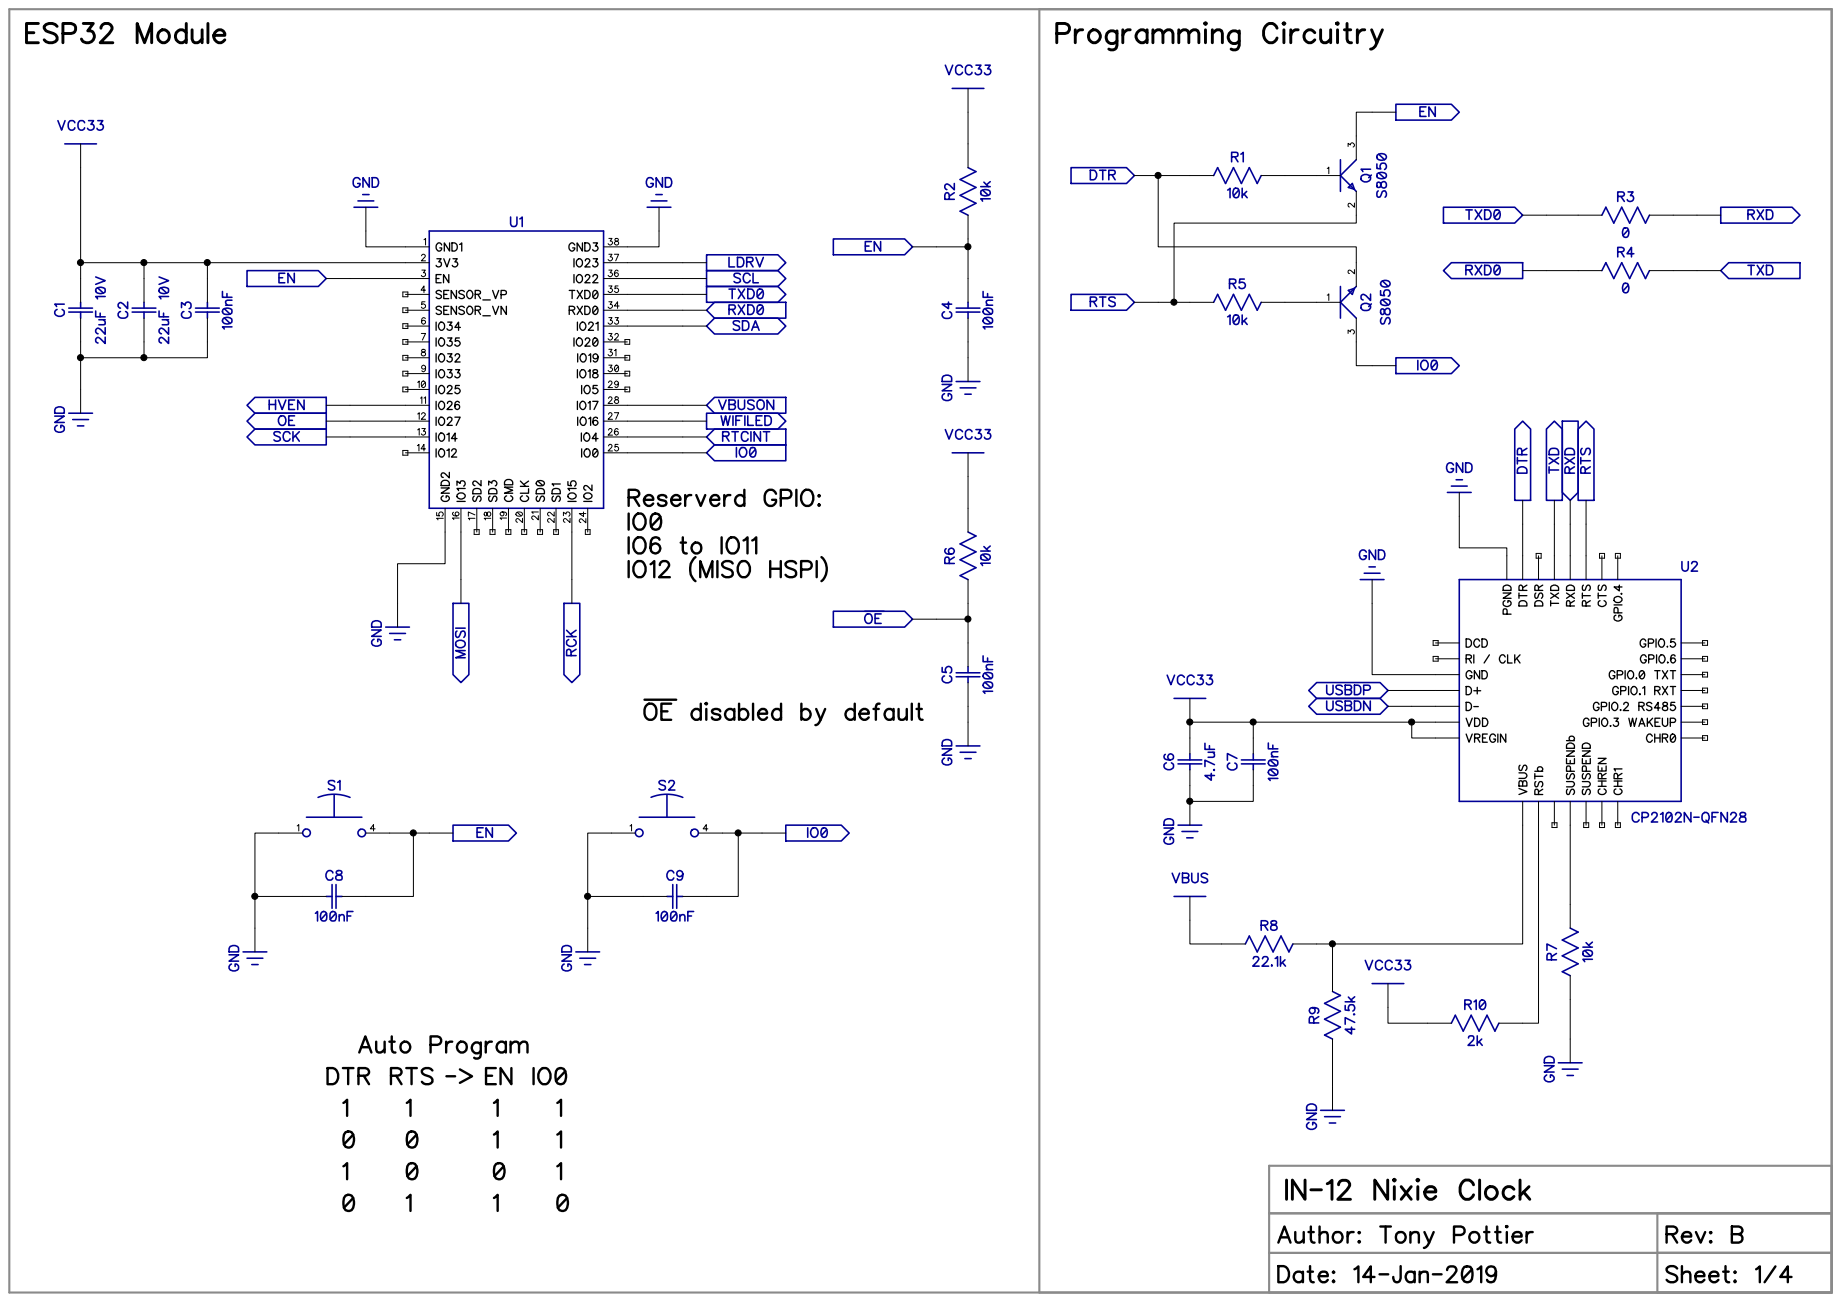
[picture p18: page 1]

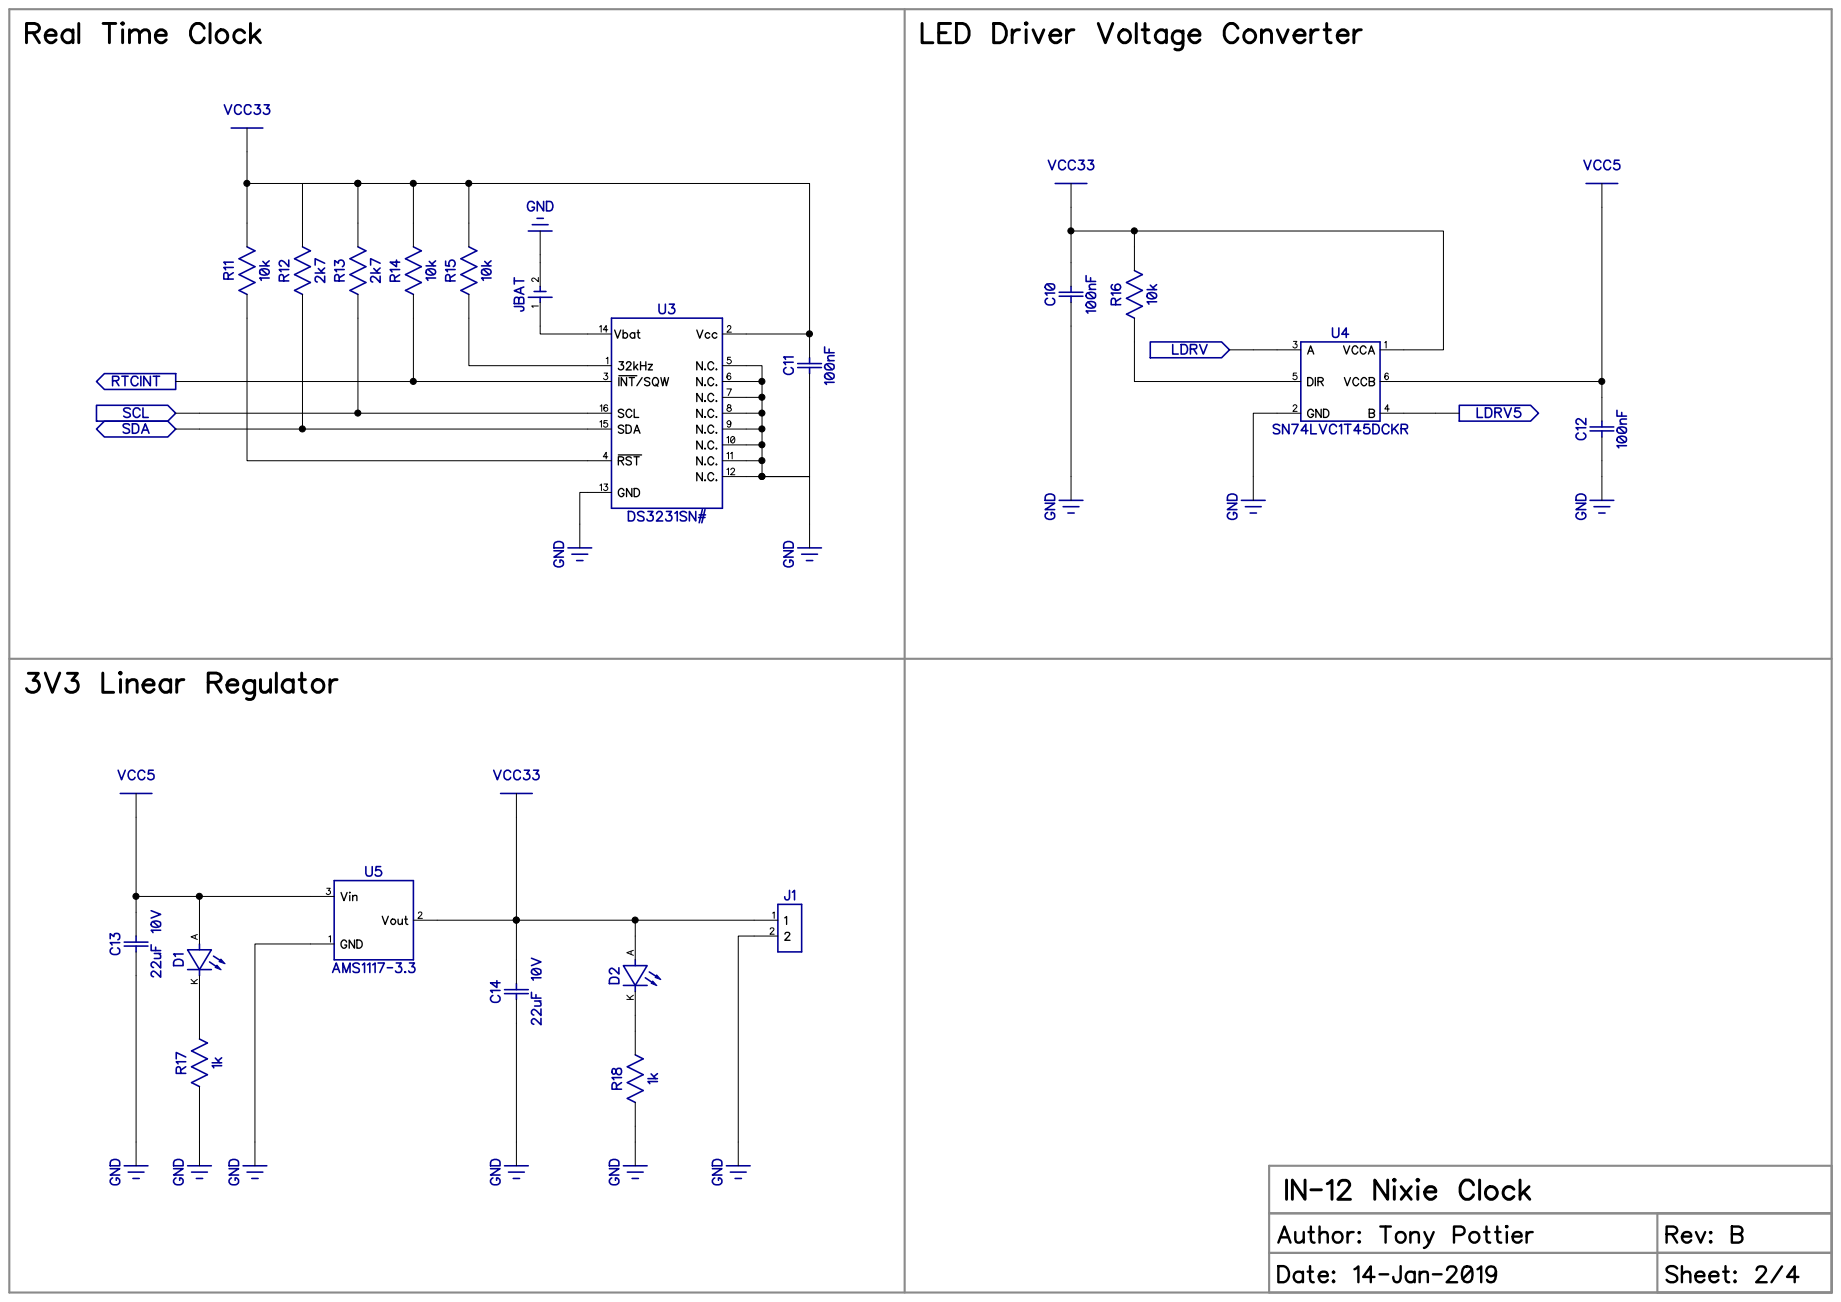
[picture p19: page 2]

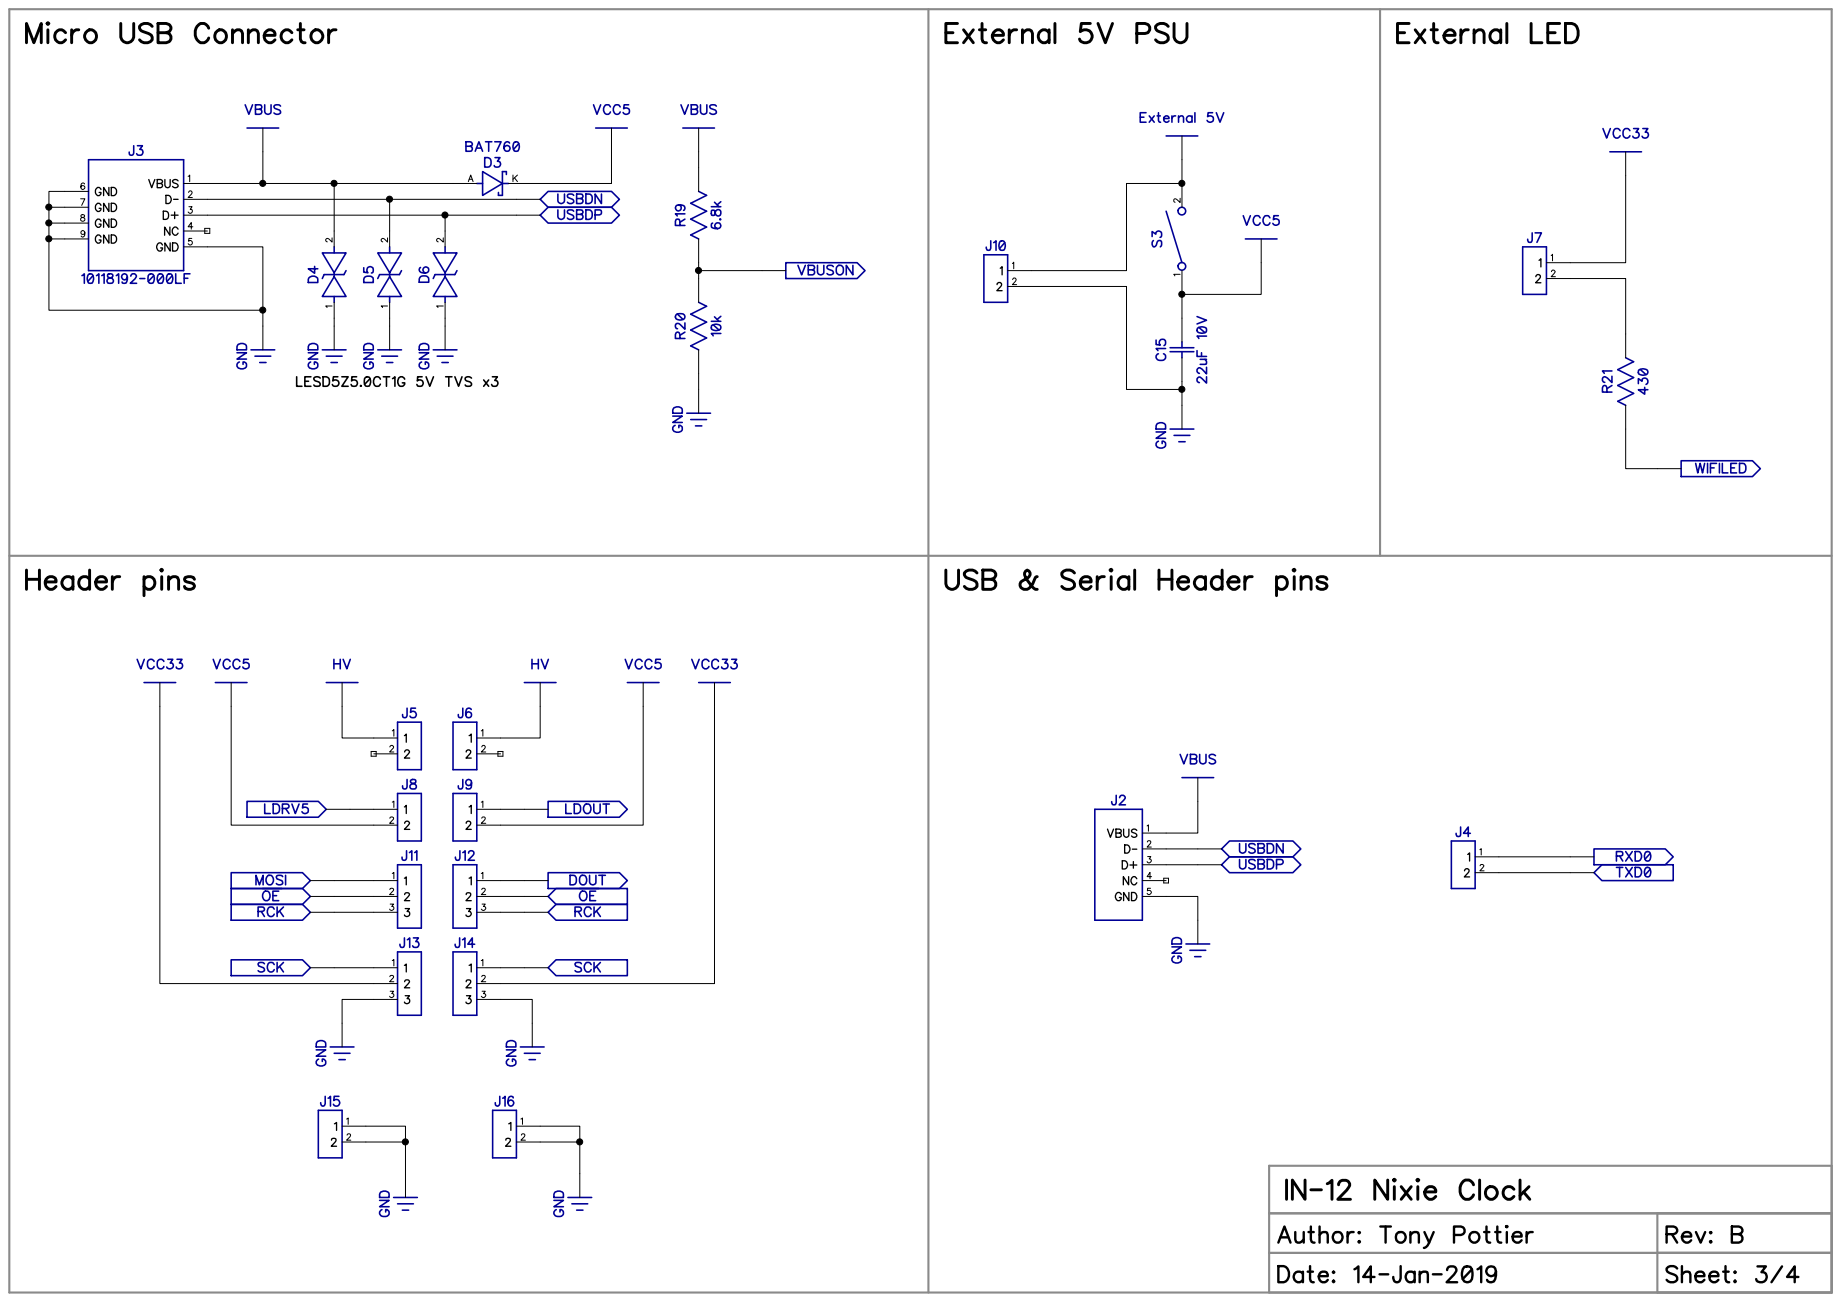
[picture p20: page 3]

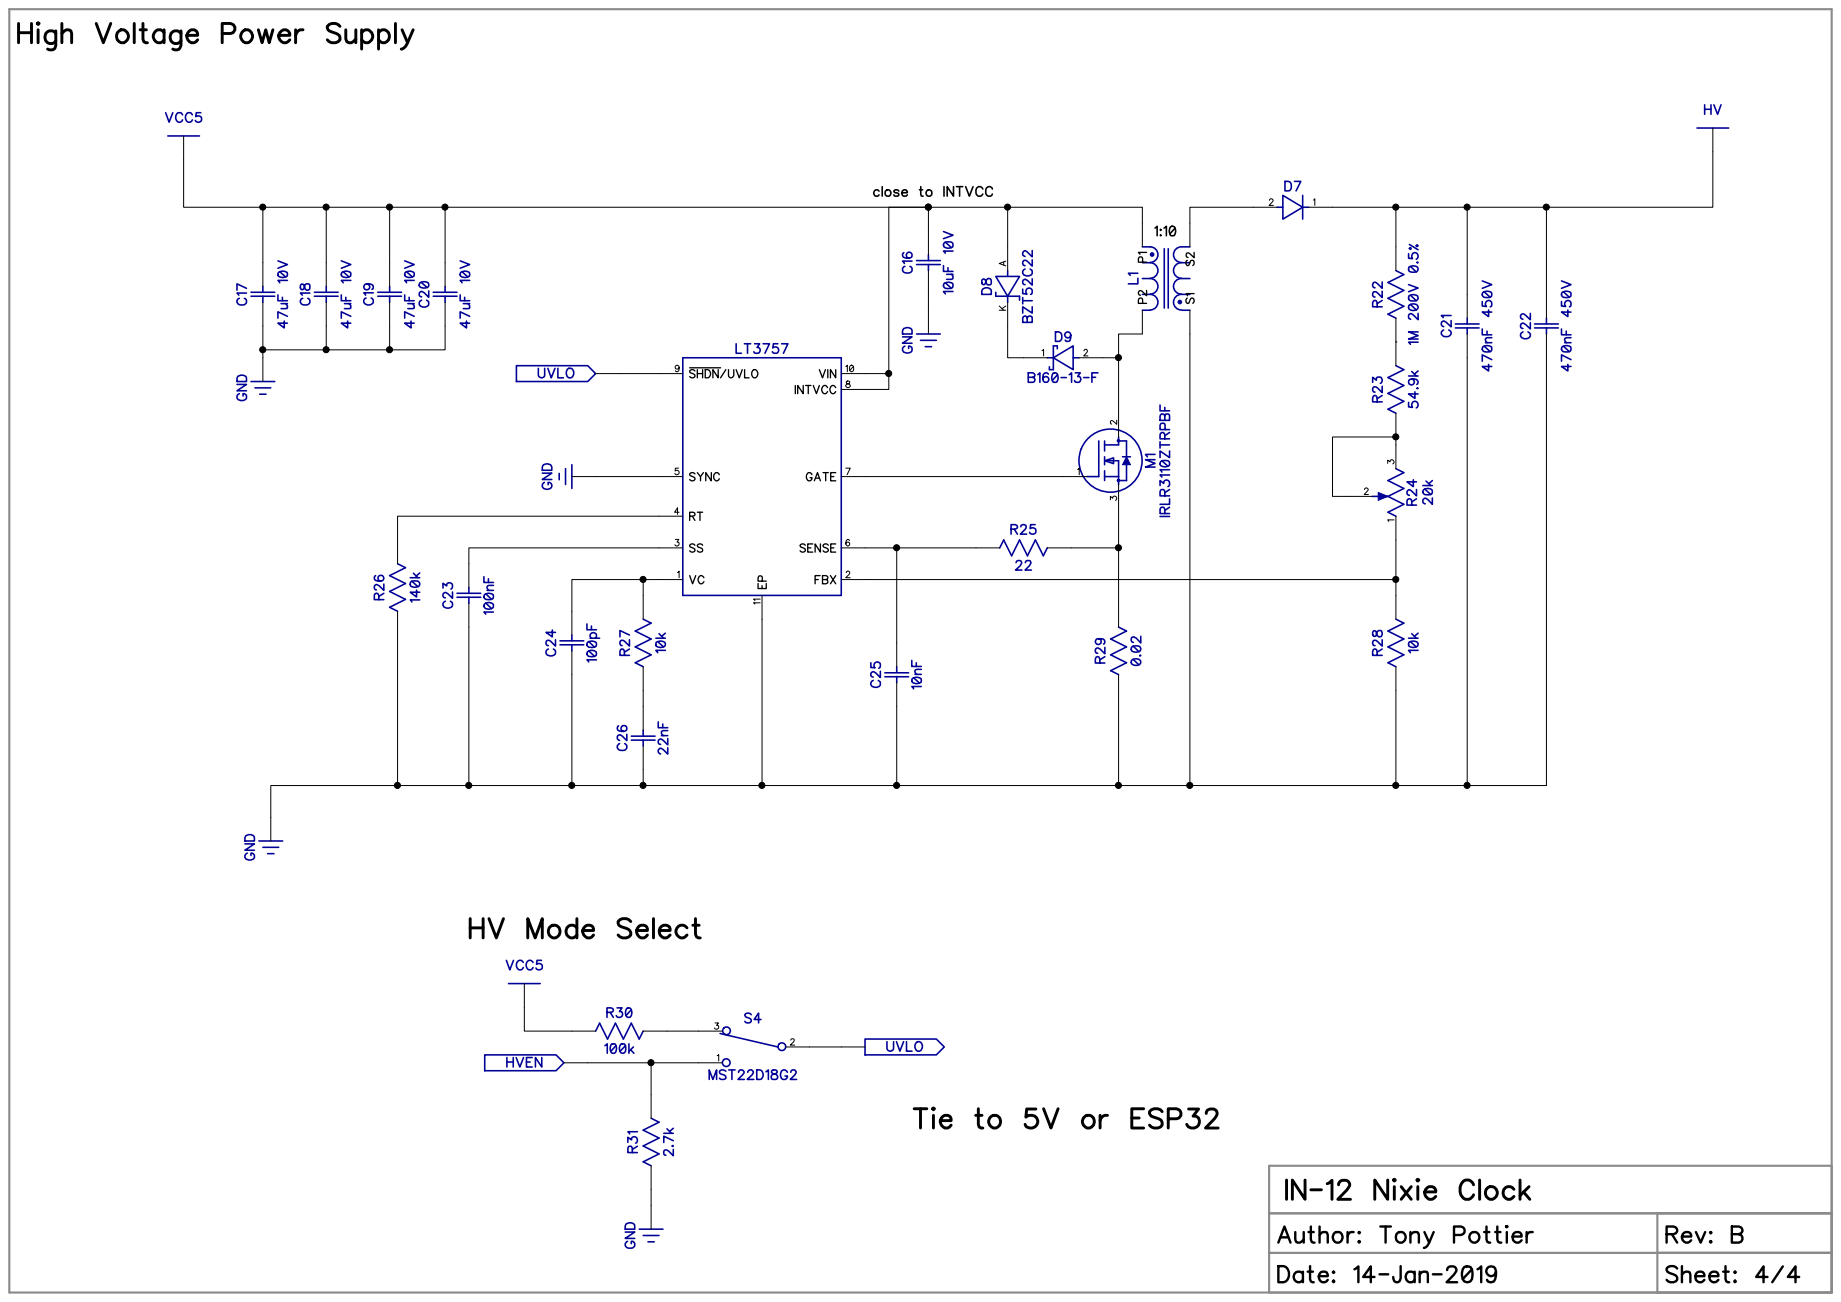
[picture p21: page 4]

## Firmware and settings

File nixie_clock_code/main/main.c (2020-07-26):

/*
Copyright (c) 2017-2019 Tony Pottier

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
@file main.c
@author Tony Pottier
@brief Entry point for the ESP32 application.
@see https://idyl.io
@see https://github.com/tonyp7/esp32-wifi-manager
*/



#include <stdio.h>
#include <string.h>
#include "freertos/FreeRTOS.h"
#include "driver/gpio.h"
#include "driver/spi_master.h"
#include "freertos/task.h"
#include "esp_system.h"
#include "esp_spi_flash.h"
#include "esp_wifi.h"
#include "esp_system.h"
#include "nvs_flash.h"
#include "esp_log.h"
#include "freertos/event_groups.h"
#include "mdns.h"
#include "lwip/api.h"
#include "lwip/err.h"
#include "lwip/netdb.h"
#include "cJSON.h"


#include "wifi_manager.h"

#include "clock.h"
#include "i2c.h"
#include "ds3231.h"
#include "display.h"
#include "ws2812.h"
#include "webapp.h"



/* @brief tag used for ESP serial console messages */
static const char TAG[] = "main";

/**
 * @brief RTOS task that periodically prints the heap memory available.
 * @note Pure debug information, should not be ever started on production code
 */
void monitoring_task(void *pvParameter)
{
  for(;;){
    ESP_LOGI(TAG, "free heap: %d",esp_get_free_heap_size());
    vTaskDelay( pdMS_TO_TICKS(20000) );
  }
}


void app_main()
{


	/* GPIO/RMT init for the WS2812 driver */
	ESP_ERROR_CHECK(ws2812_init());
	
	/* GPIO init for SPI transactions & GPIOs used to control the display */
	ESP_ERROR_CHECK(display_init());

	/* start the wifi manager */
	wifi_manager_start();
  webapp_register_handlers();

	/* register cb for internet connectivity */
	wifi_manager_set_callback(WM_EVENT_STA_GOT_IP, &clock_notify_sta_got_ip);

	/* clock task */
  xTaskCreatePinnedToCore(&clock_task, "clock_task", 16384, NULL, CLOCK_TASK_PRIORITY, NULL, 1);

	//xTaskCreatePinnedToCore(&monitoring_task, "monitoring_task", 2048, NULL, 1, NULL, 1);
}

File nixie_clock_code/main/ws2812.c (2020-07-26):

/*
Copyright (c) 2019 Tony Pottier

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
@file ws2812.c
@author Tony Pottier
@brief Provides a WS2812 "neopixel" software driver

@see https://idyl.io
@see https://github.com/tonyp7/esp32-nixie-clock

This is based of FozzTexx's public domain code on WS2812
@see https://github.com/FozzTexx/ws2812-demo

*/

#include <string.h>
#include <stdio.h>
#include <stdlib.h>
#include <math.h>
#include <freertos/FreeRTOS.h>
#include <freertos/semphr.h>
#include <freertos/queue.h>
#include <freertos/task.h>
#include <soc/rmt_struct.h>
#include <soc/dport_reg.h>
#include <driver/gpio.h>
#include <soc/gpio_sig_map.h>
#include <esp_intr_alloc.h>
#include <driver/rmt.h>
#include "esp_log.h"


#include "ws2812.h"

#define ETS_RMT_CTRL_INUM		18
#define ESP_RMT_CTRL_DISABLE	ESP_RMT_CTRL_DIABLE /* Typo in esp_intr.h */

#define DIVIDER		4 /* Above 4, timings start to deviate*/
#define DURATION	12.5 /* minimum time of a single RMT duration
				in nanoseconds based on clock */

#define PULSE_T0H						(  350 / (DURATION * DIVIDER));
#define PULSE_T1H						(  900 / (DURATION * DIVIDER));
#define PULSE_T0L						(  900 / (DURATION * DIVIDER));
#define PULSE_T1L						(  350 / (DURATION * DIVIDER));
#define PULSE_TRS						(50000 / (DURATION * DIVIDER));

#define MAX_PULSES						32

#define WS2812_RMT_CHANNEL				0

#define WS2812_QUEUE_SIZE				3

typedef union {
  struct {
    uint32_t duration0:15;
    uint32_t level0:1;
    uint32_t duration1:15;
    uint32_t level1:1;
  };
  uint32_t val;
} rmt_pulse_pair_t;

static uint8_t *ws2812_buffer = NULL;
static unsigned int ws2812_pos, ws2812_len, ws2812_half;
static xSemaphoreHandle ws2812_sem = NULL;
static intr_handle_t rmt_intr_handle = NULL;
static rmt_pulse_pair_t ws2812_bits[2];
static SemaphoreHandle_t ws2812_mutex = NULL;

static const char TAG[] = "ws2812";

QueueHandle_t ws2812_queue = NULL; 

/* the actual array holding the values of each backlight pixel */
static rgb_t *ws2812_pixels = NULL;

float clamp(float d, float min, float max) {
	const float t = d < min ? min : d;
	return t > max ? max : t;
}

/**
 * @brief RTOS task processing backlight color changes
 */
static void ws2812_task(void *pvParameters)
{
	ws2812_message_t msg;
	const uint8_t pixel_count = WS2812_STRIP_SIZE;
	rgb_t *pixels = malloc(sizeof(rgb_t) * pixel_count);
	

	for(;;) {
		if(xQueueReceive(ws2812_queue, &msg, portMAX_DELAY)) {

			ESP_LOGI(TAG, "Received R:%d G:%d B:%d", msg.rgb.r, msg.rgb.g, msg.rgb.b);

			for (uint8_t i = 0; i < pixel_count; i++) {
				pixels[i] = msg.rgb;
			}

			ws2812_set_colors(pixel_count, pixels);
		}
	}

}



float impulse( float k, float x ){
    float h = k*x;
    return h*expf(1.0f-h);
}

/**
 * @brief exponential step interp. Typical k: 10.0f. Typical n: 1.0f
 */
float exp_step(float x, float k, float n){
	return expf( -k * powf(x, n) );
}



esp_err_t ws2812_set_backlight_color(rgb_t c){

	ws2812_message_t msg;
	msg.rgb = c;

	BaseType_t ret = xQueueSend( ws2812_queue, &msg, pdMS_TO_TICKS(1000) );

	if(ret == pdTRUE){
		return ESP_OK;
	}
	else{
		return ESP_FAIL; /* ret could be errQUEUE_FULL */
	}

}


/**
 * @brief smoothstep performs smooth Hermite interpolation between 0 and 1 when edge0 < x < edge1.
 * This is useful in cases where a threshold function with a smooth transition is desired.
 */
float smoothstep(const float edge0, const float edge1, const float x){
	const float t = clamp((x - edge0) / (edge1 - edge0), 0.0f, 1.0f);
	return t * t * (3.0f - 2.0f * t);
}


/**
 * @brief initialize the RMT channel to be suitable to control a WS2812 LED
 */
void ws2812_init_rmt_channel(int rmt_channel)
{
	RMT.apb_conf.fifo_mask = 1;  /* enable memory access, instead of FIFO mode. */
	RMT.apb_conf.mem_tx_wrap_en = 1; /* wrap around when hitting end of buffer */
	RMT.conf_ch[rmt_channel].conf0.div_cnt = DIVIDER;
	RMT.conf_ch[rmt_channel].conf0.mem_size = 1;
	RMT.conf_ch[rmt_channel].conf0.carrier_en = 0;
	RMT.conf_ch[rmt_channel].conf0.carrier_out_lv = 1;
	RMT.conf_ch[rmt_channel].conf0.mem_pd = 0;

	RMT.conf_ch[rmt_channel].conf1.rx_en = 0;
	RMT.conf_ch[rmt_channel].conf1.mem_owner = 0;
	RMT.conf_ch[rmt_channel].conf1.tx_conti_mode = 0;    /* loop back mode */
	RMT.conf_ch[rmt_channel].conf1.ref_always_on = 1;    /* use APB 80Mhz clock */
	RMT.conf_ch[rmt_channel].conf1.idle_out_en = 1;
	RMT.conf_ch[rmt_channel].conf1.idle_out_lv = 0;

	return;
}

void ws2812_copy()
{
  unsigned int i, j, offset, len, bit;


  offset = ws2812_half * MAX_PULSES;
  ws2812_half = !ws2812_half;

  len = ws2812_len - ws2812_pos;
  if (len > (MAX_PULSES / 8))
    len = (MAX_PULSES / 8);

  if (!len) {
    for (i = 0; i < MAX_PULSES; i++)
      RMTMEM.chan[WS2812_RMT_CHANNEL].data32[i + offset].val = 0;
    return;
  }

  for (i = 0; i < len; i++) {
    bit = ws2812_buffer[i + ws2812_pos];
    for (j = 0; j < 8; j++, bit <<= 1) {
      RMTMEM.chan[WS2812_RMT_CHANNEL].data32[j + i * 8 + offset].val =
	ws2812_bits[(bit >> 7) & 0x01].val;
    }
    if (i + ws2812_pos == ws2812_len - 1)
      RMTMEM.chan[WS2812_RMT_CHANNEL].data32[7 + i * 8 + offset].duration1 = PULSE_TRS;
  }

  for (i *= 8; i < MAX_PULSES; i++)
    RMTMEM.chan[WS2812_RMT_CHANNEL].data32[i + offset].val = 0;

  ws2812_pos += len;
  return;
}

void ws2812_handle_interrupt(void *arg){
	BaseType_t task_awoken = 0;

  if (RMT.int_st.ch0_tx_thr_event) {
    ws2812_copy();
    RMT.int_clr.ch0_tx_thr_event = 1;
  }
  else if (RMT.int_st.ch0_tx_end && ws2812_sem) {
    xSemaphoreGiveFromISR(ws2812_sem, &task_awoken);
    RMT.int_clr.ch0_tx_end = 1;
  }

  return;
}

esp_err_t ws2812_init(){

	esp_err_t ret;

	/* mutex for the pixels memory */
	ws2812_mutex = xSemaphoreCreateMutex();

	DPORT_SET_PERI_REG_MASK(DPORT_PERIP_CLK_EN_REG, DPORT_RMT_CLK_EN);
	DPORT_CLEAR_PERI_REG_MASK(DPORT_PERIP_RST_EN_REG, DPORT_RMT_RST);

	ret = rmt_set_pin((rmt_channel_t)WS2812_RMT_CHANNEL, RMT_MODE_TX, (gpio_num_t)WS2818_DATA_GPIO);
	if(ret != ESP_OK) return ret;

	ws2812_init_rmt_channel(WS2812_RMT_CHANNEL);

	RMT.tx_lim_ch[WS2812_RMT_CHANNEL].limit = MAX_PULSES;
	RMT.int_ena.ch0_tx_thr_event = 1;
	RMT.int_ena.ch0_tx_end = 1;

	ws2812_bits[0].level0 = 1;
	ws2812_bits[0].level1 = 0;
	ws2812_bits[0].duration0 = PULSE_T0H;
	ws2812_bits[0].duration1 = PULSE_T0L;
	ws2812_bits[1].level0 = 1;
	ws2812_bits[1].level1 = 0;
	ws2812_bits[1].duration0 = PULSE_T1H;
	ws2812_bits[1].duration1 = PULSE_T1L;

	/* allocate memory for the pixels */
	ws2812_pixels = (rgb_t*)malloc(sizeof(rgb_t) * WS2812_STRIP_SIZE);


	ret = esp_intr_alloc(ETS_RMT_INTR_SOURCE, 0, ws2812_handle_interrupt, NULL, &rmt_intr_handle);

	/* create the queue */
	ws2812_queue = xQueueCreate(WS2812_QUEUE_SIZE, sizeof(ws2812_message_t));
	if(ws2812_queue == NULL){
		return ESP_ERR_NO_MEM;
	}

	if(ret == ESP_OK){
		/* spawn the task that will handle the LED backlights */
		xTaskCreatePinnedToCore(ws2812_task, "ws2812_task", 4096, NULL, 10, NULL, 0);
	}

	return ret;

}
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

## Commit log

2019-05-11 logic board renders
2019-05-23 updated to latest version of esp32-wifi-manager
2019-05-26 fixed response processing in case data is received in several chunks
2019-05-26 fix a stack overflow
    [main.c]
2019-06-02 fixed nasty infinite loop bug
    [clock.c]
2019-06-02 removed i2c init (see i2c.h)
2019-07-14 still WIP on ws2812 driver
2020-01-14 add assert in i2c ds3231 communication
2020-01-14 png schematics for convenience
2020-01-14 added clock face schematics
2020-01-14 added USB plug in safety interrupt
    When USB is connected, the nixie display will automatically shut down to avoid strain on BAT760
    [display.c, display.h]
2020-01-14 revB PCB
2020-03-02 logic board gerber
    [Through.drl, clock-logic-board.Board.gbr, clock-logic-board.BoardOutline.gbr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]
2020-03-02 clock face
    [Through.drl, top-clock-face.BoardOutline.gbr, top-clock-face.Bottom.gbr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]
2020-07-17 added dependency to esp32-wifi-manager
2020-07-25 creates a dedicated task and queue/message pump for backlights
2020-07-25 experiments with SPI instead of RMT for WS2812
2020-07-26 completely converted code to queue pump driven system
2020-08-01 occasional watchdog timer issue fixed
2020-08-03 correct handling of posting sleep mode
    [clock.c]
2020-08-08 fixed and endless SLEEP EVENT firing
    [clock.c]
